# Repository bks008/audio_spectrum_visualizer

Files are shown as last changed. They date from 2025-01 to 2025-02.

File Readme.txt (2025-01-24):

Audio Spectrum Visualizer

Samples stereo analog audio and displays the frequency response on an 8x24 dot LED display.

Inputs:
USB-C PD

R/L RCA at audio line level

USB-C comes in at 20V. 
Supply rails:
3.3V digital supply
5V display supply
+/-6V analog supplies. +/-5V after LDO

R/L RCA has two identical channels
Gain stage
Unity gain stage to add offset (0-5V signal)
Anti Aliasing Low Pass Filter stage
Sampled using ADC121S101 over SPI

Digital Section is anything in the Arduino Nano pinout/form factor. Going with an STM32 NUCLEO-L432KC

Nucleo drives LEDs using I2C to three HT16K33A (borrowing architecture from Adafruit). 

Includes rotary encoder for brightness control and pushbutton.

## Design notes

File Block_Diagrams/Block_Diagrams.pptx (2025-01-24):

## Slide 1

Board to Board Connector

USB-C Connector

Power Converters
(sheet2)

RCA Input

Op Amp Network
(Sheet3)

ADC

STM32 Nucleo

SPI

I2C

LED Matrix Driver

LED Matrix Driver

LED Matrix Driver

LED Matrix Driver

LED Matrix Driver

8x8 LED Matrix

Rotary Encoder

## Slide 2

Power Converter Chain

USB-C Connector

TPS25730SRSMR
USB-C PD Controller

20V Rail

3.3V Buck Converter

REF35250QDBVR
+2.5V V_Ref

REF35125QDBVR
+5V V_Ref

5V Buck Converter

TPS70950DBVR
+5V LDO

+6V Buck Converter

-6V Inverting Buck Converter

TPS72301DBVR
-5V LDO

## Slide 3

https://sound-au.com/project88.htm

Voltage Reference
2.5V

Voltage Reference
5V

RCA Jack Input

Line Level: -10 dBV

OPA2156
Input Buffer

6dB gain

Unity Gain, Adds Offset
From: 0V center
To: 2.5V center

Anti-aliasing Low Pass Filter

ADS7886
ADC

SPI

STM32 Nucleo

Duplicate for second channel

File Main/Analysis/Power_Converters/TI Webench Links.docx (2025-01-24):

TI Webench Links

Inverting Buck 20V -> -6V

https://webench.ti.com/appinfo/webench/scripts/SDP.cgi?ID=741779B27A96B312

Non-Inverting Buck 20V -> 6V

https://webench.ti.com/appinfo/webench/scripts/SDP.cgi?ID=59A415CA2FF1D905

Non-Inverting Buck 20V -> 3.3V

https://webench.ti.com/appinfo/webench/scripts/SDP.cgi?ID=6A7F44F1BA65E24F

Non-Inverting Buck 20V -> 5V

https://webench.ti.com/appinfo/webench/scripts/SDP.cgi?ID=DB2471651018C219

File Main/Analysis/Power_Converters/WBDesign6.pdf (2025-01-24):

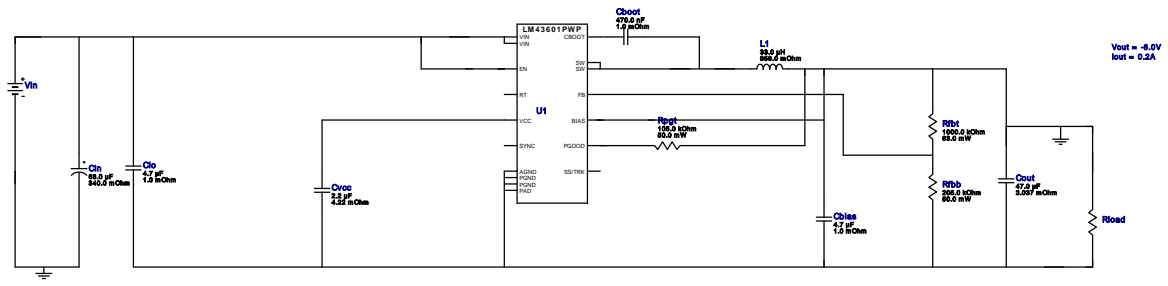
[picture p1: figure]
L1 33.0 µH 959.0 m Ohm; Cboot 470.0 nF; 1.0 m Ohm; Rfbb 205.0 kOhm 50.0 m W; CBOOT; BIAS; SYNC; VIN VIN; VCC; PGOOD; AGND; SS/TRK; PGND PGND PAD; Cin 68.0 µF; 340.0 m Ohm; Cout 47.0 µF; 3.037 m Ohm; Rfbt 1000.0 kOhm; Vout = -6.0V Iout = 0.2A; Rpgt 105.0 kOhm; Cio 4.7 µF; Cvcc; 4.22 m Ohm; Cbias; 4.7 µF 1.0 m Ohm; Vin; Rload

Copyright © 2025, Texas Instruments Incorporated | 1 | ti.com/webench

WEBENCH®
Design Report LM43601PWPR : LM43601PWPR 10V-22V to -6.00V @ 0.2A January 17, 2025 15:35:02 GMT-06:00

## WEBENCH ® Design Report

Design : 6 LM43601PWPR
LM43601PWPR 10V-22V to -6.00V @ 0.2A

VinMin = 10.0V
VinMax = 22.0V
Vout = -6.0V
Iout = 0.2A

Device = LM43601PWPR
Topology = Inverting_Buck_Boost Created = 2024-11-18 17:03:32.722 BOM Cost = $2.27
BOM Count = 11
Total Pd = 0.07W
1. The input capacitor included in the BOM only contains a small filter capacitor that should be placed near the IC. Depending on where the power supply is laid out in the system additional bulk capacitance may need to be added to filter the line ripple.
2. If there is no VinTyp specified, WEBENCH will use the VinMax value. To change the VinTyp value, click on the "Change Design Inputs" button under the Optimization Tuning knob. In some applications, while the design requires the input voltage to be a wide range, for a majority of the time, it is operating at a much lower voltage than the maximum input voltage. Sizing the inductor based on the maximum input voltage may yield an inductance much larger than typically needed, causing a larger footprint for the overall design. At the same time, components such as the input capacitor must be rated based on the maximum input voltage. WEBENCH now supports the use of this additional input voltage specification.

## Electrical BOM

Name | Manufacturer | Part Number | Properties | Qty Price | Footprint
Cbias | Taiyo Yuden | LMK212B7475KG-T (http://www.yuden.co.jp/ut/product/pdf/djmk%5Fe.pdf) Series= X7R | Cap= 4.7 uF ESR= 1.0 mOhm VDC= 10.0 V IRMS= 0.0 A
1 | $0.04
| | | | | 0805 7 mm²
Cboot | MuRata | GRM155R60J474KE19D (http://search.murata.co.jp/Ceramy/PnsearchViewAction.do) Series= X5R

Cap= 470.0 nF
ESR= 1.0 mOhm
VDC= 6.3 V
IRMS= 0.0 A

1 $0.01
0402 3 mm²
Cin | Nichicon | UUD1V680MCL1GS (http://products.nichicon.co.jp/en/pdf/XJA043/e%2Dud.pdf) Series= uD

Cap= 68.0 uF
ESR= 340.0 mOhm
VDC= 35.0 V
IRMS= 280.0 mA

1 $0.10

SM_RADIAL_6.3BMM 80
mm²
Cio | TDK | C2012X5R1H475K125AB Series= X5R

Cap= 4.7 uF
ESR= 1.0 mOhm
VDC= 50.0 V
IRMS= 4.3 A

1 $0.12
0805 7 mm²
Cout | MuRata | GRM32ER61C476KE15L (http://psearch.en.murata.com/capacitor/result/smd/?status%3Dall%26pid%3DGRM32ER61C476KE15L) Series= X5R

Cap= 47.0 uF
ESR= 3.037 mOhm
VDC= 16.0 V
IRMS= 4.59346 A

1 $0.17
1210_280 15 mm²
Cvcc | MuRata | GRM21BR71A225KA01L (http://psearch.en.murata.com/capacitor/result/smd/?status%3Dall%26pid%3DGRM21BR71A225KA01L) Series= X7R

Cap= 2.2 uF
ESR= 4.22 mOhm
VDC= 10.0 V
IRMS= 2.08454 A

1 $0.03
0805 7 mm²
L1 | Bourns | SRN3015-330M (http://www.bourns.com/data/global/pdfs/SRN3015.pdf) | L= 33.0 µH 959.0 mOhm
1 | $0.22

SRN3015 16 mm²
Rfbb | Yageo | RC0201FR-07205KL (http://www.yageo.com/exep/pages/download/literatures/PYu%2DR%5FMarking%5F2.pdf) Series= ? | Res= 205.0 kOhm Power= 50.0 mW Tolerance= 1.0%
1 | $0.01
0201 2 mm²

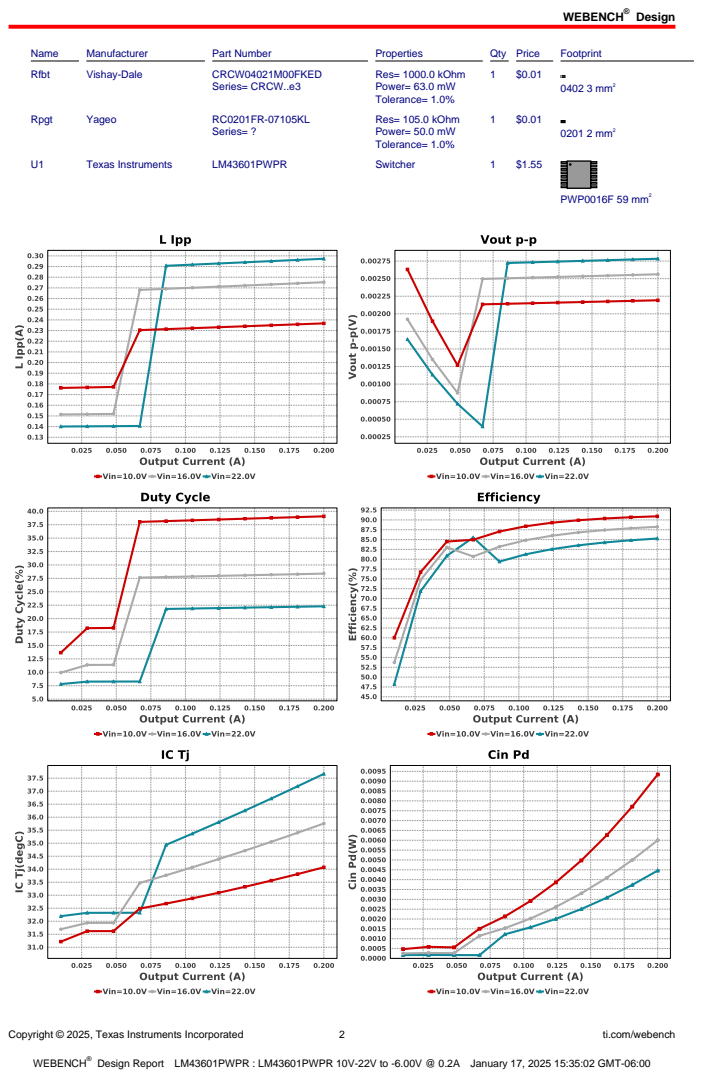
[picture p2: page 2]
Design; Copyright © 2025, Texas Instruments Incorporated; ti.com/webench; Name; Manufacturer; Part Number; Properties; Qty Price; Footprint; Rfbt; Vishay-Dale; CRCW04021M00FKED; Series= CRCW..e3; Res= 1000.0 kOhm Power= 63.0 mW Tolerance= 1.0%; 0402 3 mm²; Rpgt; Yageo; Series= ?; Res= 105.0 kOhm Power= 50.0 mW Tolerance= 1.0%; 0201 2 mm²; Texas Instruments; LM43601PWPR; Switcher; PWP0016F 59 mm²

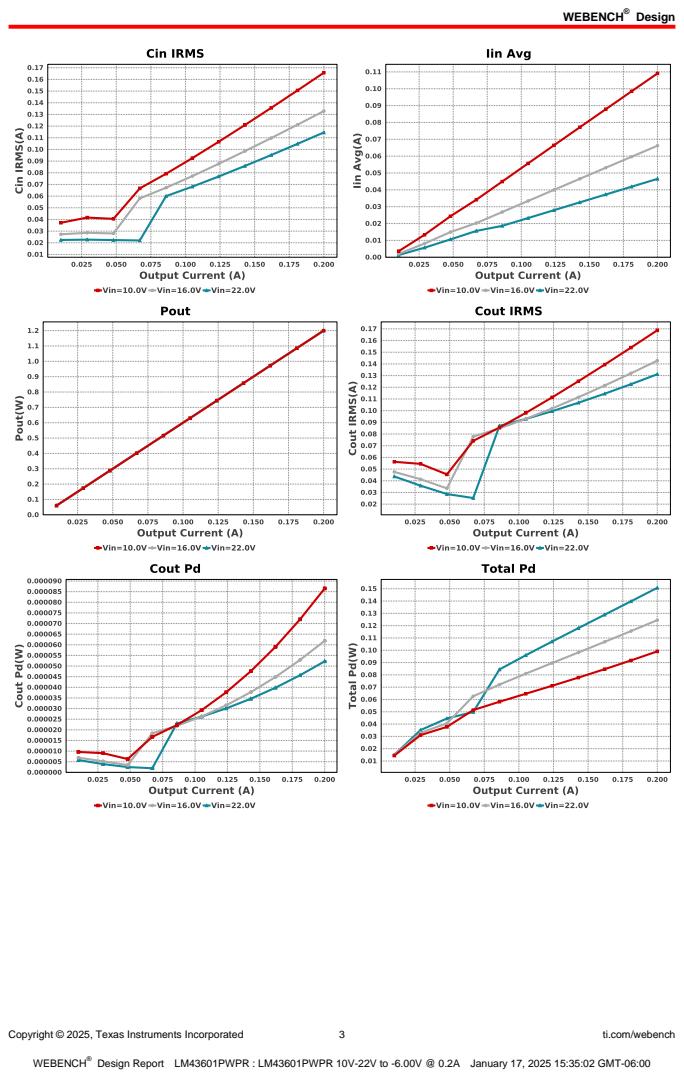
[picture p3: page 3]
Copyright © 2025, Texas Instruments Incorporated; ti.com/webench

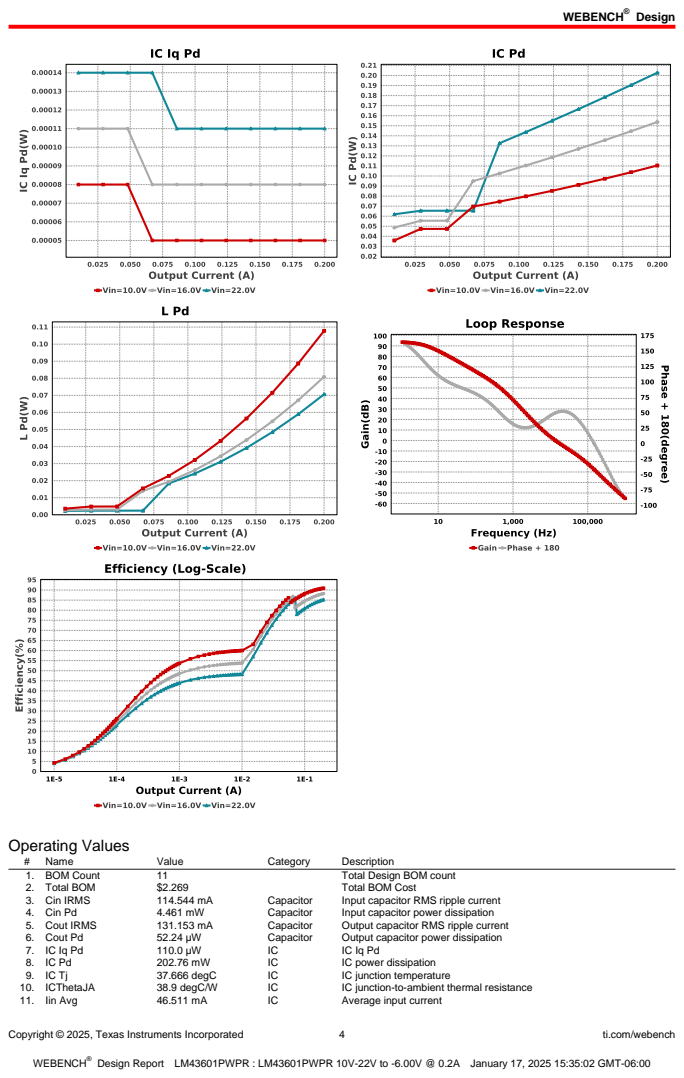
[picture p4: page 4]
Copyright © 2025, Texas Instruments Incorporated; ti.com/webench; Operating Values; Name; Value; Category; Description; 1. BOM Count; Total Design BOM count; 2. Total BOM; Total BOM Cost; 3. Cin IRMS; Capacitor; Input capacitor RMS ripple current; 4. Cin Pd; Input capacitor power dissipation; 5. Cout IRMS; Output capacitor RMS ripple current; 6. Cout Pd; Output capacitor power dissipation; IC power dissipation; 37.666 degC; IC junction temperature; 10. ICThetaJA; 38.9 degC/W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

Copyright © 2025, Texas Instruments Incorporated | 5 | ti.com/webench
# | Name | Value | Category | Description

12. L Ipp | 297.293 mA | Inductor | Peak-to-peak inductor ripple current
13. L Pd | 70.597 mW | Inductor | Inductor power dissipation
14. Cin Pd | 4.461 mW | Power | Input capacitor power dissipation
15. Cout Pd | 52.24 µW | Power | Output capacitor power dissipation
16. IC Pd | 202.76 mW | Power | IC power dissipation
17. L Pd | 70.597 mW | Power | Inductor power dissipation
18. Total Pd | 68.515 mW | Power | Total Power Dissipation
19. Cross Freq | 13.664 kHz | System
| | | Information | Bode plot crossover frequency
20. Duty Cycle | 22.297 % | System
| | | Information | Duty cycle
21. Efficiency | 85.269 % | System
| | | Information | Steady state efficiency
22. FootPrint | 200.0 mm² | System
| | | Information | Total Foot Print Area of BOM components
23. Frequency | 500.0 kHz | System
| | | Information | Switching frequency
24. Gain Marg | -27.732 dB | System
| | | Information | Bode Plot Gain Margin
25. Iout | 200.0 mA | System
| | | Information | Iout operating point
26. Low Freq Gain | 93.543 dB | System
| | | Information | Gain at 1Hz
27. Mode | CCM | System
| | | Information | Conduction Mode
28. Phase Marg | 50.083 deg | System
| | | Information | Bode Plot Phase Margin
29. Pout | 1.2 W | System
| | | Information | Total output power
30. Vin | 10.0 V | System
| | | Information | Vin operating point
31. Vout | -6.0 V | System
| | | Information | Operational Output Voltage
32. Vout Actual | 5.972 V | System
| | | Information | Vout Actual calculated based on selected voltage divider resistors
33. Vout Tolerance | 3.978 % | System
| | | Information | Vout Tolerance based on IC Tolerance (no load) and voltage divider resistors if applicable
34. Vout p-p | 2.783 mV | System
| | | Information | Peak-to-peak output ripple voltage

## Design Inputs

Name | Value | Description
| Iout | | 200.0 m | Maximum Output Current
VinMax | 22.0 | Maximum input voltage
VinMin | 10.0 | Minimum input voltage
Vout | -6.0 | Output Voltage
| base_pn | | LM43601 | Base Product Number
source | DC | Input Source Type
Ta | 30.0 | Ambient temperature


Copyright © 2025, Texas Instruments Incorporated | 6 | ti.com/webench

## Assembly

## Component Testing

Some published data on components in datasheets such as Capacitor ESR and Inductor DC resistance is based on conservative values that will guarantee that the components always exceed the specification. For design purposes it is usually better to work with typical values. Since this data is not always available it is a good practice to measure the Capacitance and ESR values of Cin and Cout, and the inductance and DC resistance of L1 before assembly of the board. Any large discrepancies in values should be electrically simulated in WEBENCH to check for instabilities and thermally simulated in WebTHERM to make sure critical temperatures are not exceeded.

## Soldering Component to Board

If board assembly is done in house it is best to tack down one terminal of a component on the board then solder the other terminal. For surface mount parts with large tabs, such as the DPAK, the tab on the back of the package should be pre-tinned with solder, then tacked into place by one of the pins. To solder the tab town to the board place the iron down on the board while resting against the tab, heating both surfaces simultaneously. Apply light pressure to the top of the plastic case until the solder flows around the part and the part is flush with the PCB. If the solder is not flowing around the board you may need a higher wattage iron (generally 25W to 30W is enough).

## Initial Startup of Circuit

It is best to initially power up the board by setting the input supply voltage to the lowest operating input voltage 10.0V and set the input supply's current limit to zero. With the input supply off connect up the input supply to Vin and GND. Connect a digital volt meter and a load if needed to set the minimum Iout of the design from Vout and GND. Turn on the input supply and slowly turn up the current limit on the input supply.
If the voltage starts to rise on the input supply continue increasing the input supply current limit while watching the output voltage. If the current increases on the input supply, but the voltage remains near zero, then there may be a short or a component misplaced on the board. Power down the board and visually inspect for solder bridges and recheck the diode and capacitor polarities. Once the power supply circuit is operational then more extensive testing may include full load testing, transient load and line tests to compare with simulation results.

## Load Testing

The setup is the same as the initial startup, except that an additional digital voltmeter is connected between Vin and GND, a load is connected between Vout and GND and a current meter is connected in series between Vout and the load. The load must be able to handle at least rated output power + 50% ( 7.5 watts for this design). Ideally the load is supplied in the form of a variable load test unit. It can also be done in the form of suitably large power resistors. When using an oscilloscope to measure waveforms on the prototype board, the ground leads of the oscilloscope probes should be as short as possible and the area of the loop formed by the ground lead should be kept to a minimum. This will help reduce ground lead inductance and eliminate EMI noise that is not actually present in the circuit.

## Design Assistance

1. Master key : C6AE7176C9723757[v1]
2. LM43601 Product Folder : http://www.ti.com/product/LM43601 : contains the data sheet and other resources.

Copyright © 2025, Texas Instruments Incorporated | 7 | ti.com/webench

Important Notice and Disclaimer

TI provides technical and reliability data (including datasheets), design resources (including reference designs), application or other design advice, web tools, safety information, and other resources AS IS and with all faults, and disclaims all warranties. These resources are intended for skilled developers designing with TI products. You are solely responsible for (1) selecting the appropriate TI products for your application, (2) designing, validating and testing your application, and (3) ensuring your application meets applicable standards, and any other safety, security, or other requirements.

These resources are subject to change without notice. TI grants you permission to use these resources only for development of an application that uses the TI products described in the resource. Other reproduction and display of these resources is prohibited. No license is granted to any other TI intellectual property right or to any third party intellectual property right. TI disclaims responsibility for, and you will fully indemnify TI and its representatives against, any claims, damages, costs, losses, and liabilities arising out of your use of these resources.

Providing these resources does not expand or otherwise alter TI's applicable Terms of Sale or other applicable terms available either on ti.com or provided in conjunction with TI products.

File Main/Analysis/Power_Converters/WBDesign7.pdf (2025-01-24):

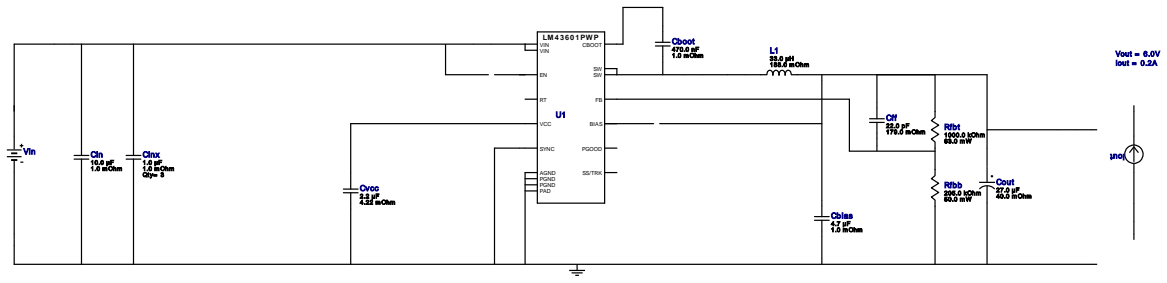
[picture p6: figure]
Cout 27.0 µF; 40.0 m Ohm; L1 33.0 µH 188.0 m Ohm; Rfbt 1000.0 kOhm; Cinx 1.0 µF 1.0 m Ohm; Qty= 3; Rfbb; 205.0 kOhm 50.0 m W; Cboot 470.0 nF; 1.0 m Ohm; Cin 10.0 µF 1.0 m Ohm; Cvcc 2.2 µF 4.22 m Ohm; CBOOT; BIAS; SYNC; VIN VIN; VCC; PGOOD; AGND; SS/TRK; PGND PGND PAD; Vout = 6.0V Iout = 0.2A; Cbias 4.7 µF 1.0 m Ohm; Cff 22.0 pF; 179.0 m Ohm; Vin; Iout

Copyright © 2025, Texas Instruments Incorporated | 1 | ti.com/webench

WEBENCH®
Design Report LM43601PWPR : LM43601PWPR 10V-22V to 6.00V @ 0.2A January 17, 2025 15:37:10 GMT-06:00

## WEBENCH ® Design Report

Design : 7 LM43601PWPR
LM43601PWPR 10V-22V to 6.00V @ 0.2A

VinMin = 10.0V
VinMax = 22.0V
Vout = 6.0V
Iout = 0.2A

Device = LM43601PWPR
Topology = Buck
Created = 2024-11-18 17:06:33.048 BOM Cost = $2.77
BOM Count = 13
Total Pd = 0.15W
1. The input capacitor included in the BOM only contains a small filter capacitor that should be placed near the IC. Depending on where the power supply is laid out in the system additional bulk capacitance may need to be added to filter the line ripple.
2. If there is no VinTyp specified, WEBENCH will use the VinMax value. To change the VinTyp value, click on the "Change Design Inputs" button under the Optimization Tuning knob. In some applications, while the design requires the input voltage to be a wide range, for a majority of the time, it is operating at a much lower voltage than the maximum input voltage. Sizing the inductor based on the maximum input voltage may yield an inductance much larger than typically needed, causing a larger footprint for the overall design. At the same time, components such as the input capacitor must be rated based on the maximum input voltage. WEBENCH now supports the use of this additional input voltage specification.

## Electrical BOM

Name | Manufacturer | Part Number | Properties | Qty Price | Footprint
Cbias | Taiyo Yuden | LMK212B7475KG-T (http://www.yuden.co.jp/ut/product/pdf/djmk%5Fe.pdf) Series= X7R | Cap= 4.7 uF ESR= 1.0 mOhm VDC= 10.0 V IRMS= 0.0 A
1 | $0.04
| | | | | 0805 7 mm²
Cboot | MuRata | GRM155R60J474KE19D (http://search.murata.co.jp/Ceramy/PnsearchViewAction.do) Series= X5R

Cap= 470.0 nF
ESR= 1.0 mOhm
VDC= 6.3 V
IRMS= 0.0 A

1 $0.01
0402 3 mm²
Cff | Kemet | C0805C220J5GACTU (http://capacitoredge.kemet.com/capedge2/DataSheet/Datasheet%2DC0805C220J5GACTU.pdf?pn%3DC0805C220J5GACTU) Series= C0G/NP0

Cap= 22.0 pF
ESR= 179.0 mOhm
VDC= 50.0 V
IRMS= 464.0 mA

1 $0.01
0805 7 mm²
Cin | TDK | C3225X7R1H106M250AC Series= X7R

Cap= 10.0 uF
ESR= 1.0 mOhm
VDC= 50.0 V
IRMS= 5.0 A

1 $0.27
1210 15 mm²
Cinx | Taiyo Yuden | GMK212B7105KG-T (http://www.yuden.co.jp/ut/product/pdf/djmk%5Fe.pdf) Series= X7R

Cap= 1.0 uF
ESR= 1.0 mOhm
VDC= 35.0 V
IRMS= 0.0 A

3 $0.04
0805 7 mm²
Cout | Panasonic | 25SVPF27MX Series= SVPF

Cap= 27.0 uF
ESR= 40.0 mOhm
VDC= 25.0 V
IRMS= 2.45 A

1 $0.47

CAPSMT_62_E61 53 mm²

Cvcc | MuRata | GRM21BR71A225KA01L (http://psearch.en.murata.com/capacitor/result/smd/?status%3Dall%26pid%3DGRM21BR71A225KA01L) Series= X7R

Cap= 2.2 uF
ESR= 4.22 mOhm
VDC= 10.0 V
IRMS= 2.08454 A

1 $0.03
0805 7 mm²
L1 | Bourns | SRN6045-330M (http://www.bourns.com/data/global/pdfs/SRN6045.pdf) | L= 33.0 µH 188.0 mOhm
1 | $0.25

SRN6045 64 mm²

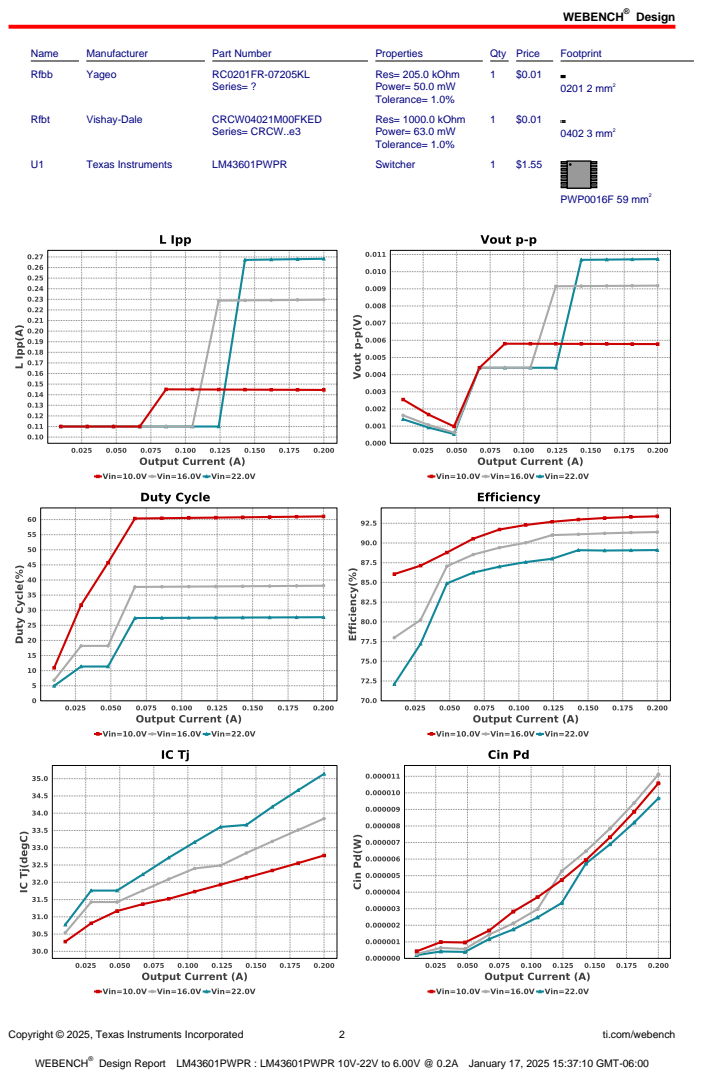
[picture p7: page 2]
Design; Copyright © 2025, Texas Instruments Incorporated; ti.com/webench; Name; Manufacturer; Part Number; Properties; Qty Price; Footprint; Rfbb; Yageo; Series= ?; Res= 205.0 kOhm Power= 50.0 mW Tolerance= 1.0%; 0201 2 mm²; Rfbt; Vishay-Dale; CRCW04021M00FKED; Series= CRCW..e3; Res= 1000.0 kOhm Power= 63.0 mW Tolerance= 1.0%; 0402 3 mm²; Texas Instruments; LM43601PWPR; Switcher; PWP0016F 59 mm²

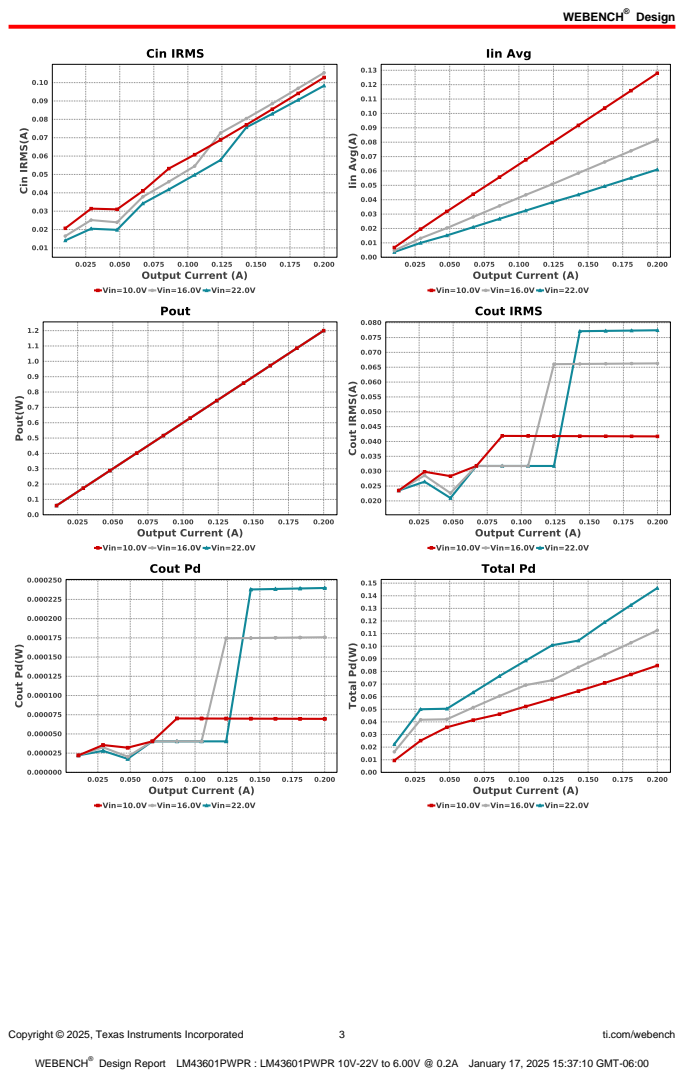
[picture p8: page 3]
Copyright © 2025, Texas Instruments Incorporated; ti.com/webench

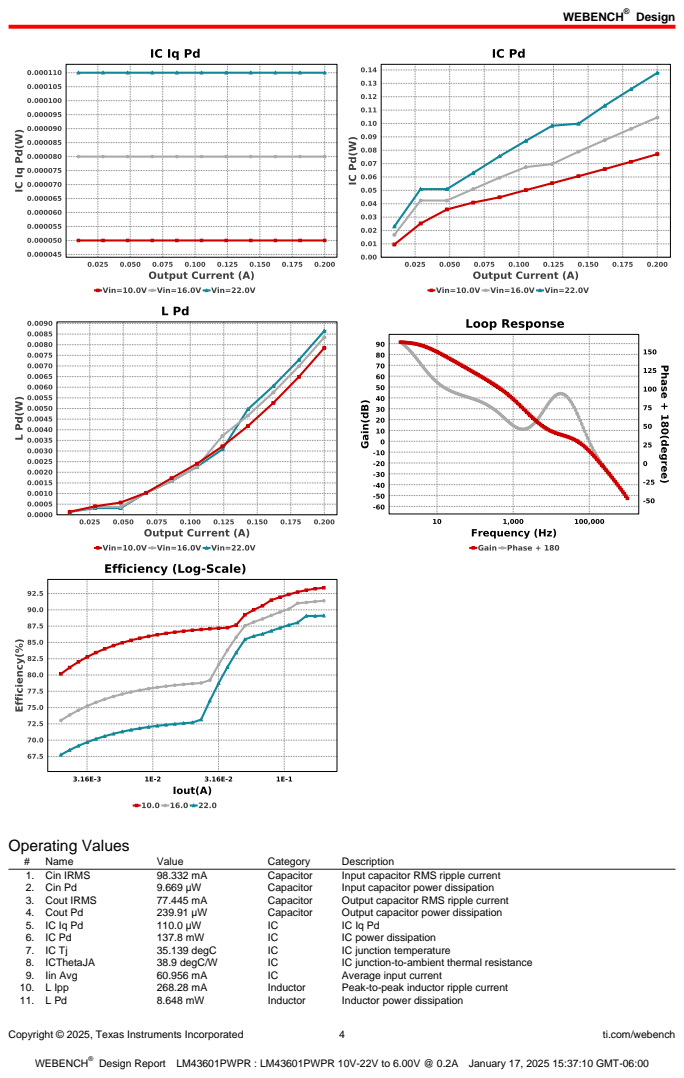
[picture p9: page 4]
Copyright © 2025, Texas Instruments Incorporated; ti.com/webench; Operating Values; Name; Value; Category; Description; 1. Cin IRMS; Capacitor; Input capacitor RMS ripple current; 2. Cin Pd; Input capacitor power dissipation; 3. Cout IRMS; Output capacitor RMS ripple current; 4. Cout Pd; Output capacitor power dissipation; IC power dissipation; 35.139 degC; IC junction temperature; 8. ICThetaJA; 38.9 degC/W; IC junction-to-ambient thermal resistance; 9. Iin Avg; Average input current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

Copyright © 2025, Texas Instruments Incorporated | 5 | ti.com/webench
# | Name | Value | Category | Description

12. Cin Pd | 9.669 µW | Power | Input capacitor power dissipation
13. Cout Pd | 239.91 µW | Power | Output capacitor power dissipation
14. IC Pd | 137.8 mW | Power | IC power dissipation
15. L Pd | 8.648 mW | Power | Inductor power dissipation
16. Total Pd | 146.105 mW | Power | Total Power Dissipation
17. BOM Count | 13 | System
| | | Information | Total Design BOM count
18. Cross Freq | 48.533 kHz | System
| | | Information | Bode plot crossover frequency
19. Duty Cycle | 27.687 % | System
| | | Information | Duty cycle
20. Efficiency | 89.105 % | System
| | | Information | Steady state efficiency
21. FootPrint | 239.0 mm² | System
| | | Information | Total Foot Print Area of BOM components
22. Frequency | 500.0 kHz | System
| | | Information | Switching frequency
23. Gain Marg | -22.122 dB | System
| | | Information | Bode Plot Gain Margin
24. Iout | 200.0 mA | System
| | | Information | Iout operating point
25. Low Freq Gain | 91.3 dB | System
| | | Information | Gain at 1Hz
26. Mode | CCM | System
| | | Information | Conduction Mode
27. Phase Marg | 66.734 deg | System
| | | Information | Bode Plot Phase Margin
28. Pout | 1.2 W | System
| | | Information | Total output power
29. Total BOM | $2.77 | System
| | | Information | Total BOM Cost
30. Vin | 22.0 V | System
| | | Information | Vin operating point
31. Vout | 6.0 V | System
| | | Information | Operational Output Voltage
32. Vout Actual | 5.972 V | System
| | | Information | Vout Actual calculated based on selected voltage divider resistors
33. Vout Tolerance | 3.978 % | System
| | | Information | Vout Tolerance based on IC Tolerance (no load) and voltage divider resistors if applicable
34. Vout p-p | 10.731 mV | System
| | | Information | Peak-to-peak output ripple voltage

## Design Inputs

Name | Value | Description
| Iout | | 200.0 m | Maximum Output Current
VinMax | 22.0 | Maximum input voltage
VinMin | 10.0 | Minimum input voltage
Vout | 6.0 | Output Voltage
| base_pn | | LM43601 | Base Product Number
source | DC | Input Source Type
Ta | 30.0 | Ambient temperature


Copyright © 2025, Texas Instruments Incorporated | 6 | ti.com/webench

## Assembly

## Component Testing

Some published data on components in datasheets such as Capacitor ESR and Inductor DC resistance is based on conservative values that will guarantee that the components always exceed the specification. For design purposes it is usually better to work with typical values. Since this data is not always available it is a good practice to measure the Capacitance and ESR values of Cin and Cout, and the inductance and DC resistance of L1 before assembly of the board. Any large discrepancies in values should be electrically simulated in WEBENCH to check for instabilities and thermally simulated in WebTHERM to make sure critical temperatures are not exceeded.

## Soldering Component to Board

If board assembly is done in house it is best to tack down one terminal of a component on the board then solder the other terminal. For surface mount parts with large tabs, such as the DPAK, the tab on the back of the package should be pre-tinned with solder, then tacked into place by one of the pins. To solder the tab town to the board place the iron down on the board while resting against the tab, heating both surfaces simultaneously. Apply light pressure to the top of the plastic case until the solder flows around the part and the part is flush with the PCB. If the solder is not flowing around the board you may need a higher wattage iron (generally 25W to 30W is enough).

## Initial Startup of Circuit

It is best to initially power up the board by setting the input supply voltage to the lowest operating input voltage 10.0V and set the input supply's current limit to zero. With the input supply off connect up the input supply to Vin and GND. Connect a digital volt meter and a load if needed to set the minimum Iout of the design from Vout and GND. Turn on the input supply and slowly turn up the current limit on the input supply.
If the voltage starts to rise on the input supply continue increasing the input supply current limit while watching the output voltage. If the current increases on the input supply, but the voltage remains near zero, then there may be a short or a component misplaced on the board. Power down the board and visually inspect for solder bridges and recheck the diode and capacitor polarities. Once the power supply circuit is operational then more extensive testing may include full load testing, transient load and line tests to compare with simulation results.

## Load Testing

The setup is the same as the initial startup, except that an additional digital voltmeter is connected between Vin and GND, a load is connected between Vout and GND and a current meter is connected in series between Vout and the load. The load must be able to handle at least rated output power + 50% ( 7.5 watts for this design). Ideally the load is supplied in the form of a variable load test unit. It can also be done in the form of suitably large power resistors. When using an oscilloscope to measure waveforms on the prototype board, the ground leads of the oscilloscope probes should be as short as possible and the area of the loop formed by the ground lead should be kept to a minimum. This will help reduce ground lead inductance and eliminate EMI noise that is not actually present in the circuit.

## Design Assistance

1. Master key : C6AE7176C9723757[v1]
2. LM43601 Product Folder : http://www.ti.com/product/LM43601 : contains the data sheet and other resources.

Copyright © 2025, Texas Instruments Incorporated | 7 | ti.com/webench

Important Notice and Disclaimer

TI provides technical and reliability data (including datasheets), design resources (including reference designs), application or other design advice, web tools, safety information, and other resources AS IS and with all faults, and disclaims all warranties. These resources are intended for skilled developers designing with TI products. You are solely responsible for (1) selecting the appropriate TI products for your application, (2) designing, validating and testing your application, and (3) ensuring your application meets applicable standards, and any other safety, security, or other requirements.

These resources are subject to change without notice. TI grants you permission to use these resources only for development of an application that uses the TI products described in the resource. Other reproduction and display of these resources is prohibited. No license is granted to any other TI intellectual property right or to any third party intellectual property right. TI disclaims responsibility for, and you will fully indemnify TI and its representatives against, any claims, damages, costs, losses, and liabilities arising out of your use of these resources.

Providing these resources does not expand or otherwise alter TI's applicable Terms of Sale or other applicable terms available either on ti.com or provided in conjunction with TI products.

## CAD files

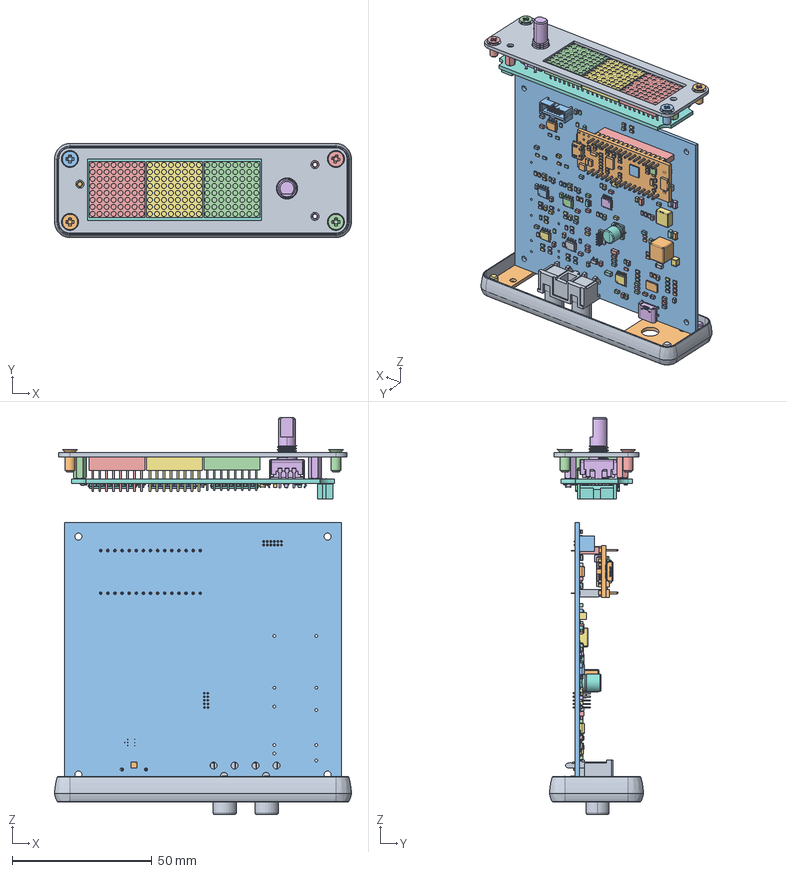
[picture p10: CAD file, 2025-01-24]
CAD/Final_Assy.FCStd
106.1 x 33.6 x 141.8 mm
L Bezel Open001
1455 screw
1455 screw001
1455 screw002
1455 screw003
1455 screw004
1455 screw005
1455 screw006
1455 screw007
mb1180c
qfn_STM32L412KBU6U
LD39050PU33R-Nucleo
STM32F103CBT6-nucleo
header x2
R_0805_2012Metric
SSOP_24_39x87mm_P0635mm
C_0805_2012Metric
C_0805_2012Metric225
R_0805_2012Metric268
R_0805_2012Metric269
D_SOD_523
R_0805_2012Metric270
C_0805_2012Metric226
SSOP_24_39x87mm_P0635mm001
R_0805_2012Metric271
R_0805_2012Metric272
R_0805_2012Metric273
D_SOD_524
R_0805_2012Metric274
D_SOD_525
C_0805_2012Metric227
C_0805_2012Metric228
C_0805_2012Metric229
R_0805_2012Metric275
C_0805_2012Metric230
R_0805_2012Metric276
R_0805_2012Metric277
C_0805_2012Metric231
R_0805_2012Metric278
SHF-106-01-L-D-TH-TR
R_0805_2012Metric279
C_0805_2012Metric232
SSOP_24_39x87mm_P0635mm002
PEC11R-4215F-S0024
_autosave-Display_PCB
C_0805_2012Metric242
C_0805_2012Metric243
C_0805_2012Metric244
TSSOP_16_44x5mm_P065mm
R_0805_2012Metric293
R_0805_2012Metric294
R_0805_2012Metric295
R_0805_2012Metric296
R_0805_2012Metric297
R_0805_2012Metric298
R_0805_2012Metric299
R_0805_2012Metric300
SOIC_8_39x49mm_P127mm
C_0805_2012Metric245
R_0805_2012Metric301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

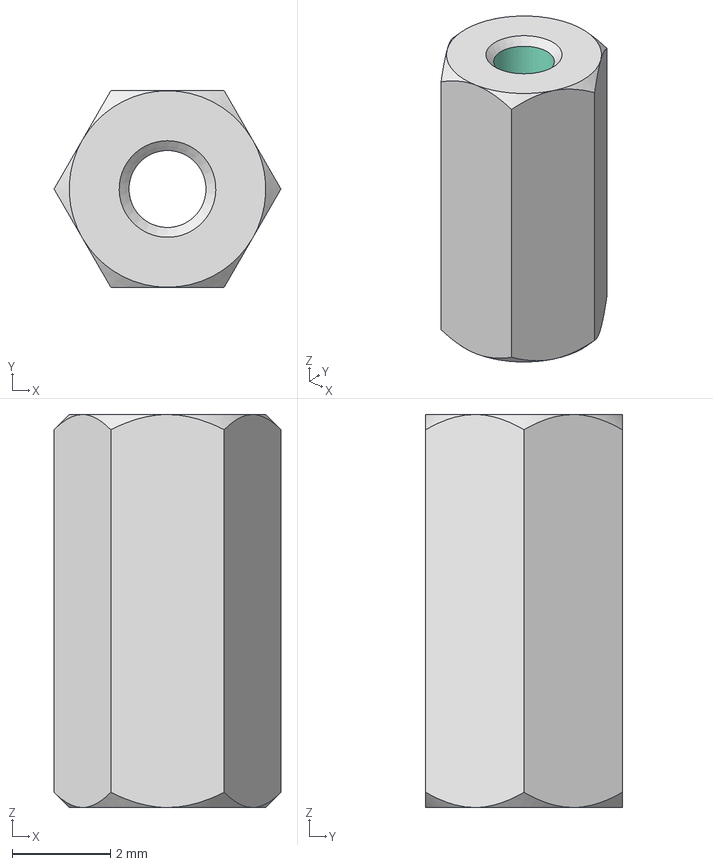
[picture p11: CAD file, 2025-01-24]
CAD/Download_STEP_970080244 (rev1).stp
4.62 x 4.00 x 8.00 mm

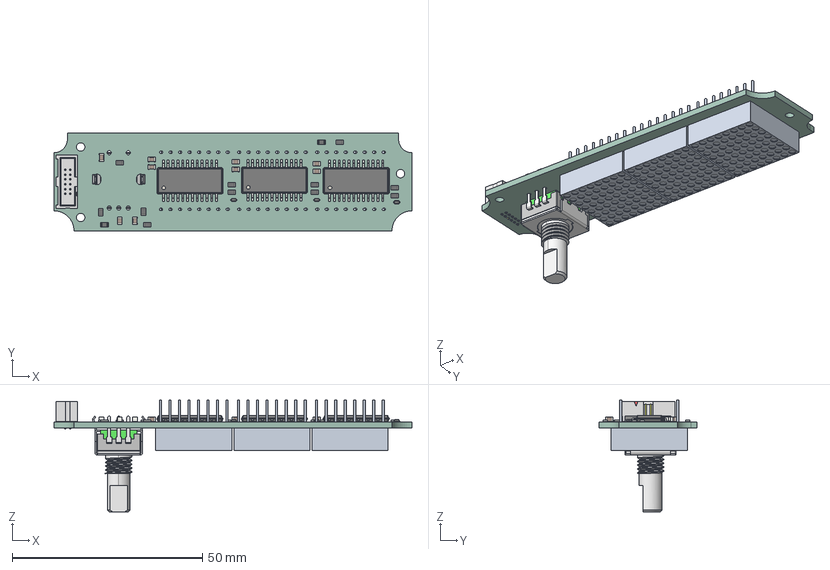
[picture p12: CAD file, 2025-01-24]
Display/Display.step
94.0 x 25.6 x 29.4 mm
R_0805_2012Metric x 13
SSOP_24_39x87mm_P0635mm x 3
C_0805_2012Metric x 9
D_SOD_523 x 3
SHF-106-01-L-D-TH-TR
PEC11R-4215F-S0024
_autosave-Display_PCB

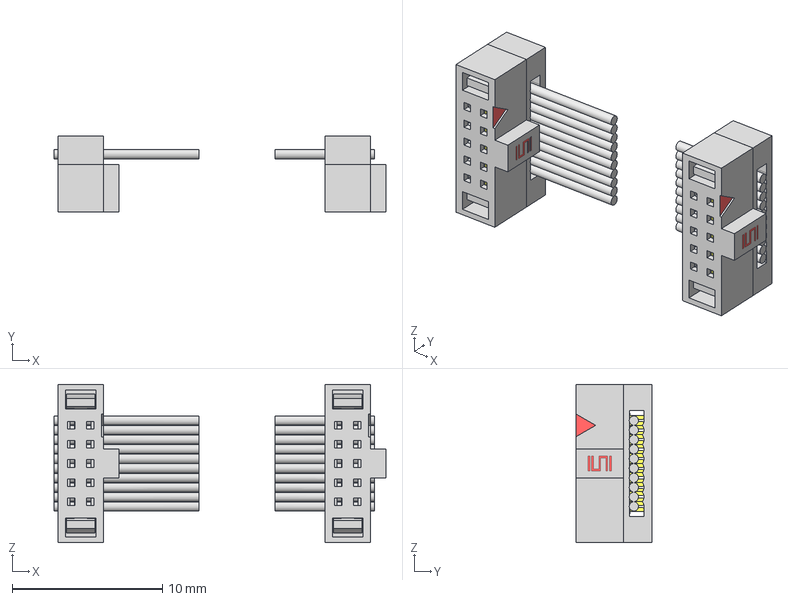
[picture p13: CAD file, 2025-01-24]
CAD/FFSD-05-D-06.00-01-N.stp
22.1 x 5.08 x 10.5 mm
FFSD-050LB x 2
FFSD-05()ub
FFSD-05pin x 4
FFSD-050se_ub

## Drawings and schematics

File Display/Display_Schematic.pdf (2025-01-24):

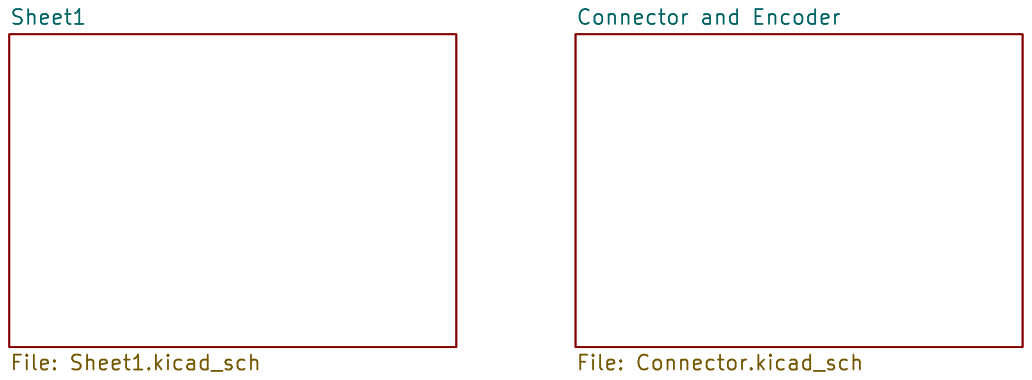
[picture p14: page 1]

Id: 1/3 Title: File: Display.kicad_sch Sheet: /

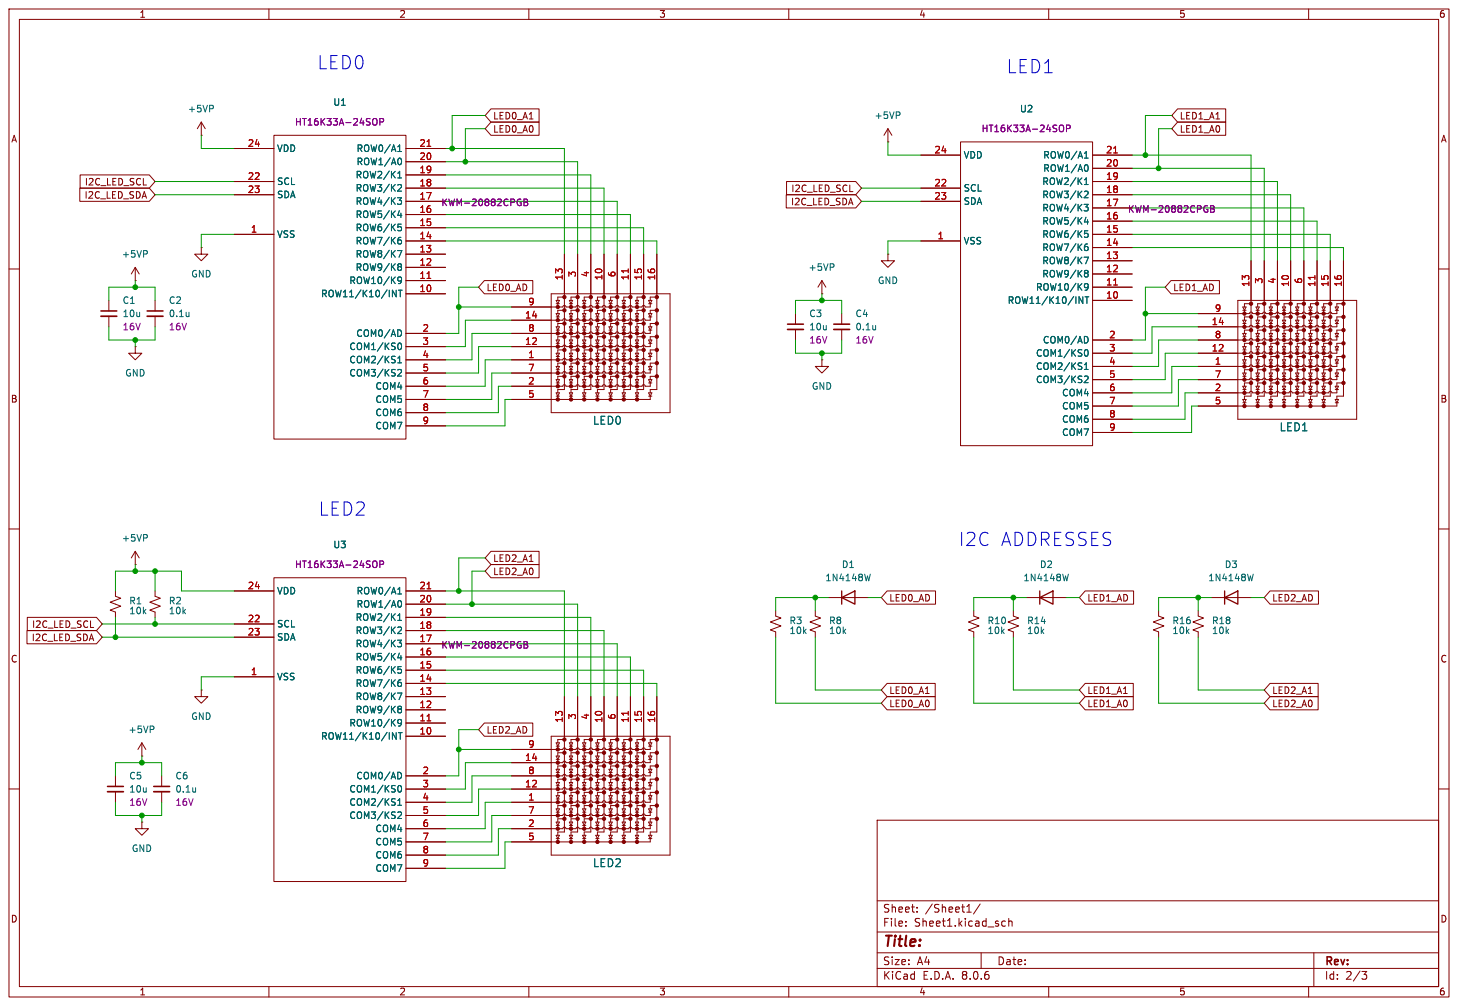
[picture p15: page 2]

Id: 2/3 Title: File: Sheet1.kicad_sch Sheet: /Sheet1/

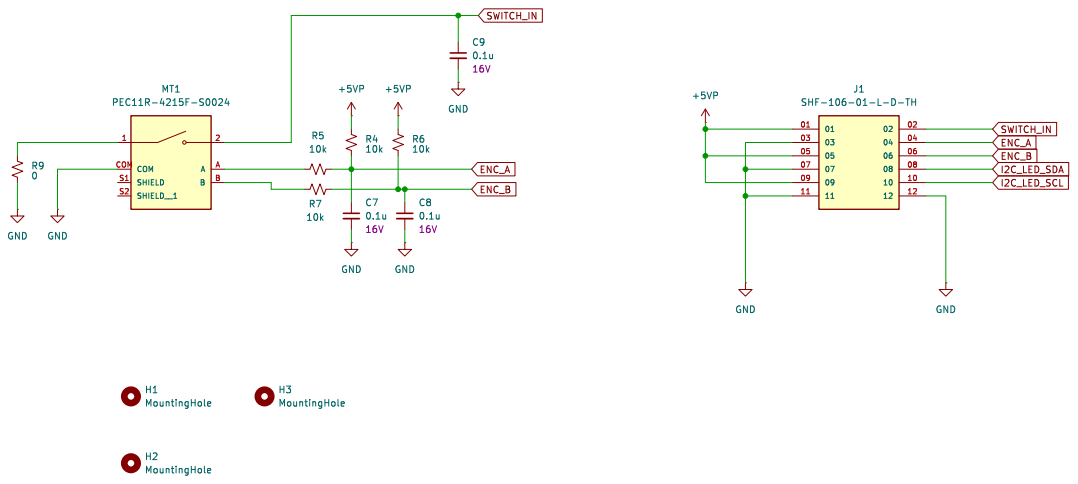
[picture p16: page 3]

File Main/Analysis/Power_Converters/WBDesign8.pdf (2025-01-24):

## WEBENCH ® Design Report

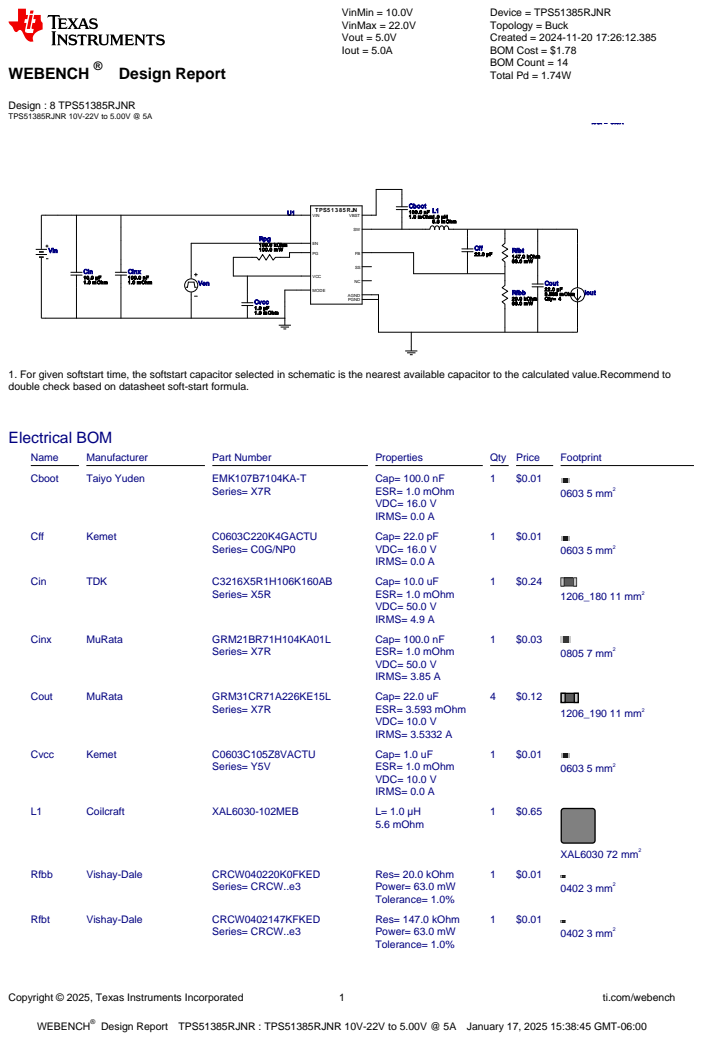
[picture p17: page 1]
Copyright © 2025, Texas Instruments Incorporated; ti.com/webench; WEBENCH®; Design : 8 TPS51385RJNR TPS51385RJNR 10V-22V to 5.00V @ 5A; VinMin = 10.0V VinMax = 22.0V Vout = 5.0V Iout = 5.0A; Device = TPS51385RJNR Topology = Buck Created = 2024-11-20 17:26:12.385 BOM Cost = $1.78 BOM Count = 14 Total Pd = 1.74W; TPS5 1 3 8 5 RJN VIN; PGND; VBST; VCC; AGND; MODE; Cinx 100.0 nF 1.0 m Ohm; Cin 10.0 µF; 1.0 m Ohm; Ven; Cvcc 1.0 µF 1.0 m Ohm; Cff 22.0 pF; L1 1.0 µH 5.6 m Ohm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

1. For given softstart time, the softstart capacitor selected in schematic is the nearest available capacitor to the calculated value.Recommend to
double check based on datasheet soft-start formula.

Design Report TPS51385RJNR : TPS51385RJNR 10V-22V to 5.00V @ 5A January 17, 2025 15:38:45 GMT-06:00

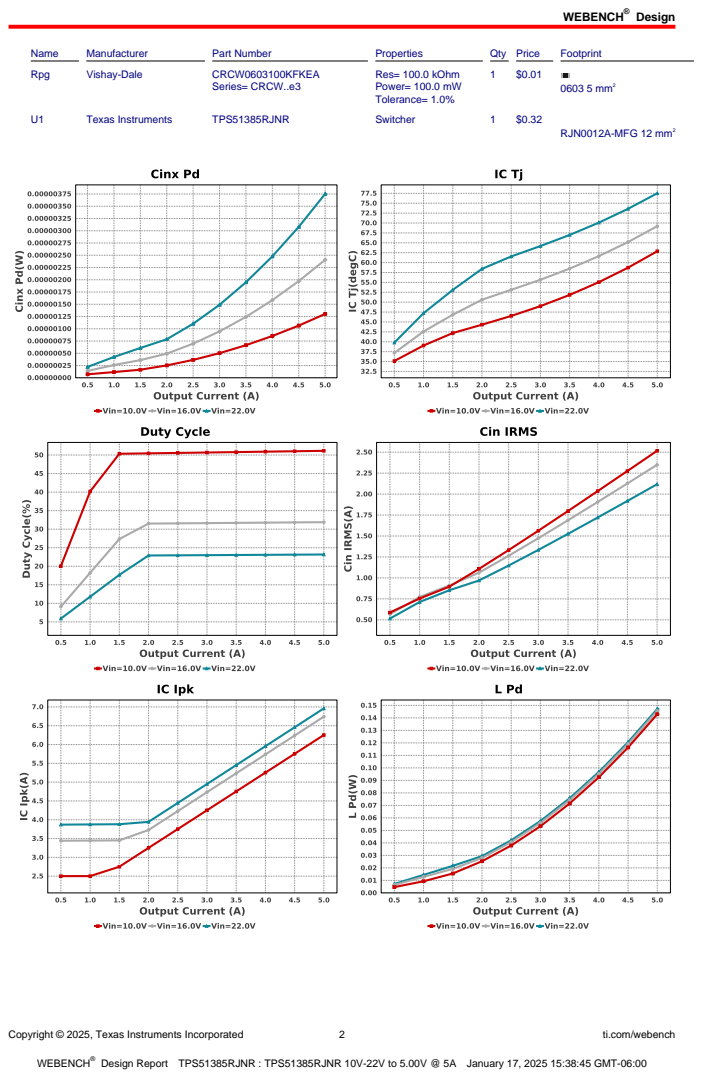
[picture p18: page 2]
Design; Copyright © 2025, Texas Instruments Incorporated; ti.com/webench; Name; Manufacturer; Part Number; Properties; Qty Price; Footprint; Rpg; Vishay-Dale; CRCW0603100KFKEA; Series= CRCW..e3; Res= 100.0 kOhm Power= 100.0 mW Tolerance= 1.0%; 0603 5 mm²; Texas Instruments; TPS51385RJNR; Switcher; RJN0012A-MFG 12 mm²

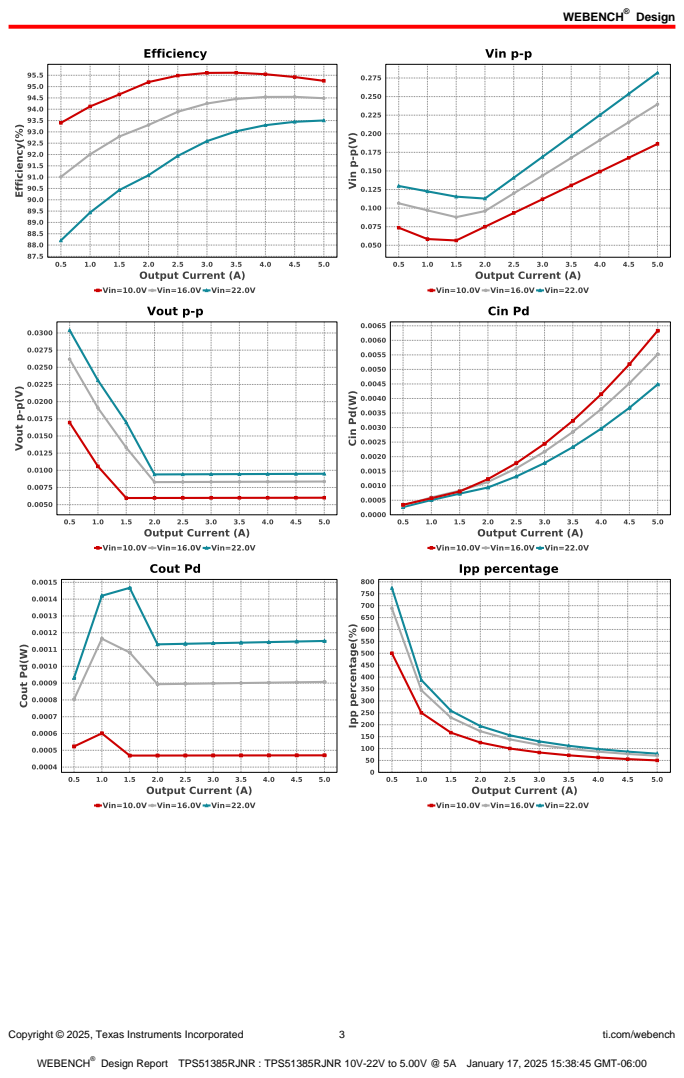
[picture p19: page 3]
Copyright © 2025, Texas Instruments Incorporated; ti.com/webench

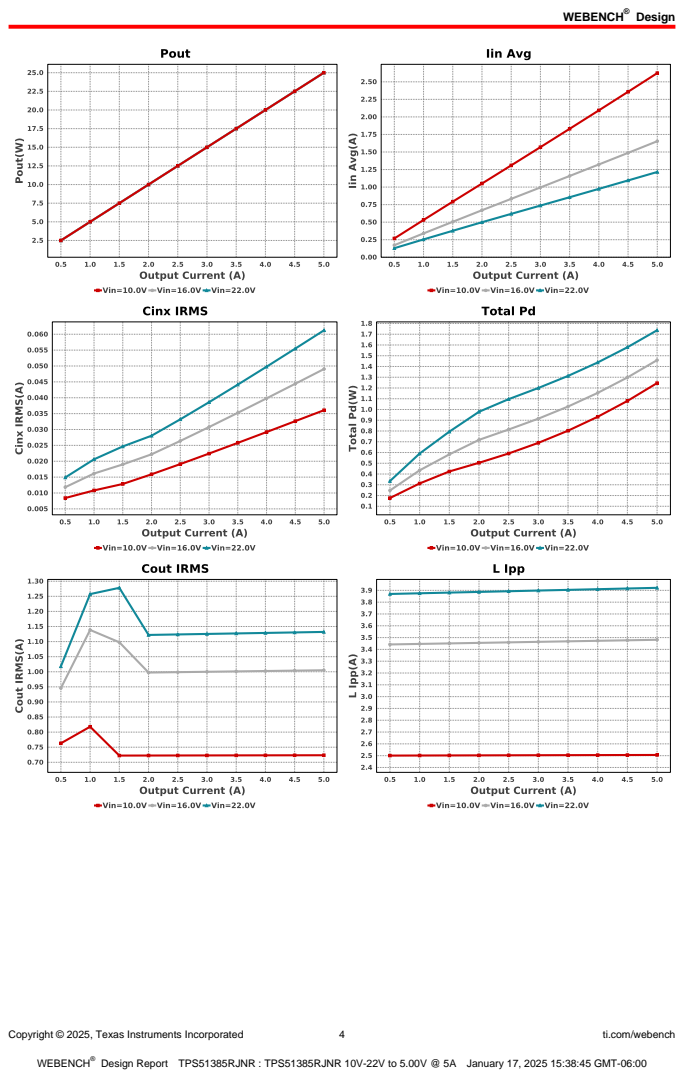
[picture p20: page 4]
Copyright © 2025, Texas Instruments Incorporated; ti.com/webench

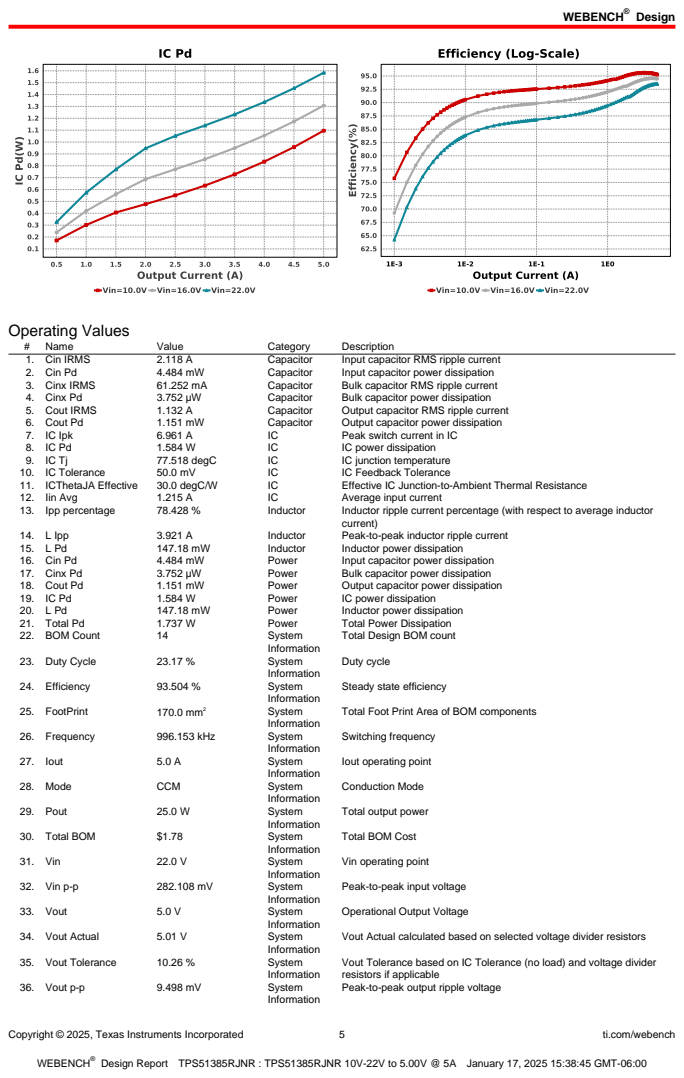
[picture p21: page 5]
Copyright © 2025, Texas Instruments Incorporated; ti.com/webench; Operating Values; Name; Value; Category; Description; 1. Cin IRMS; Capacitor; Input capacitor RMS ripple current; 2. Cin Pd; Input capacitor power dissipation; 3. Cinx IRMS; Bulk capacitor RMS ripple current; 4. Cinx Pd; Bulk capacitor power dissipation; 5. Cout IRMS; Output capacitor RMS ripple current; 6. Cout Pd; Output capacitor power dissipation; 7. IC Ipk; Peak switch current in IC; IC power dissipation; 77.518 degC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

Total Design BOM count

Steady state efficiency

Total Foot Print Area of BOM components

Iout operating point

Total output power

Total BOM Cost

Vin operating point

Peak-to-peak input voltage

Operational Output Voltage

Vout Actual calculated based on selected voltage divider resistors

Vout Tolerance based on IC Tolerance (no load) and voltage divider
resistors if applicable
Peak-to-peak output ripple voltage

Copyright © 2025, Texas Instruments Incorporated | 6 | ti.com/webench
# | Name | Value | Category | Description

37. SoftStart Time Actual 0.0 s | Softstart Time (Calculated)

## Design Inputs

Name | Value | Description
Iout | 5.0 | Maximum Output Current
VinMax | 22.0 | Maximum input voltage
VinMin | 10.0 | Minimum input voltage
Vout | 5.0 | Output Voltage
| base_pn | | TPS51385 | Base Product Number
source | DC | Input Source Type
Ta | 30.0 | Ambient temperature


Copyright © 2025, Texas Instruments Incorporated | 7 | ti.com/webench

## Assembly

## Component Testing

Some published data on components in datasheets such as Capacitor ESR and Inductor DC resistance is based on conservative values that will guarantee that the components always exceed the specification. For design purposes it is usually better to work with typical values. Since this data is not always available it is a good practice to measure the Capacitance and ESR values of Cin and Cout, and the inductance and DC resistance of L1 before assembly of the board. Any large discrepancies in values should be electrically simulated in WEBENCH to check for instabilities and thermally simulated in WebTHERM to make sure critical temperatures are not exceeded.

## Soldering Component to Board

If board assembly is done in house it is best to tack down one terminal of a component on the board then solder the other terminal. For surface mount parts with large tabs, such as the DPAK, the tab on the back of the package should be pre-tinned with solder, then tacked into place by one of the pins. To solder the tab town to the board place the iron down on the board while resting against the tab, heating both surfaces simultaneously. Apply light pressure to the top of the plastic case until the solder flows around the part and the part is flush with the PCB. If the solder is not flowing around the board you may need a higher wattage iron (generally 25W to 30W is enough).
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

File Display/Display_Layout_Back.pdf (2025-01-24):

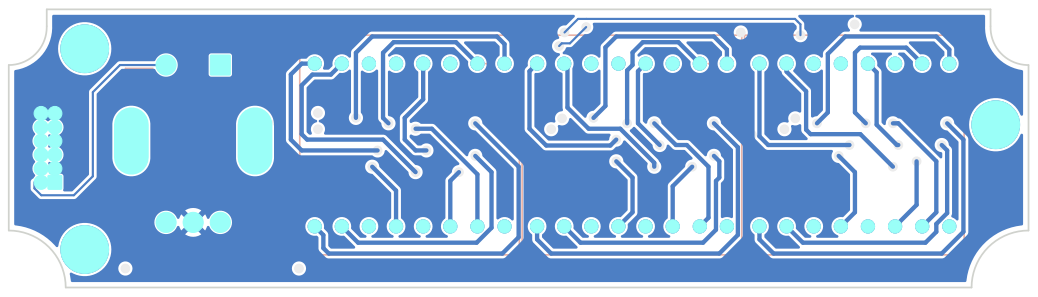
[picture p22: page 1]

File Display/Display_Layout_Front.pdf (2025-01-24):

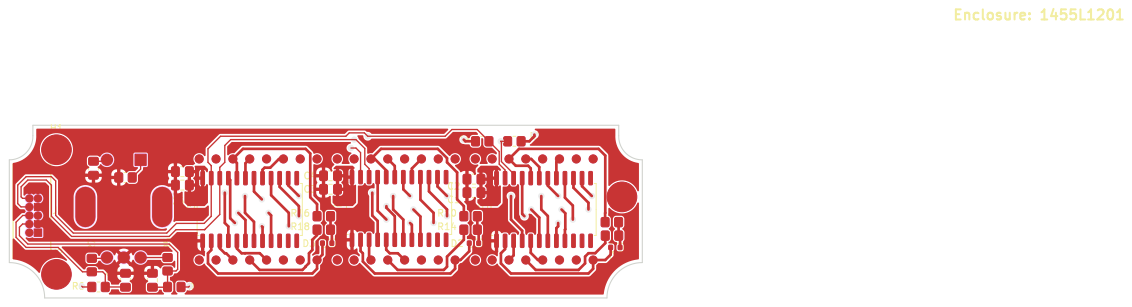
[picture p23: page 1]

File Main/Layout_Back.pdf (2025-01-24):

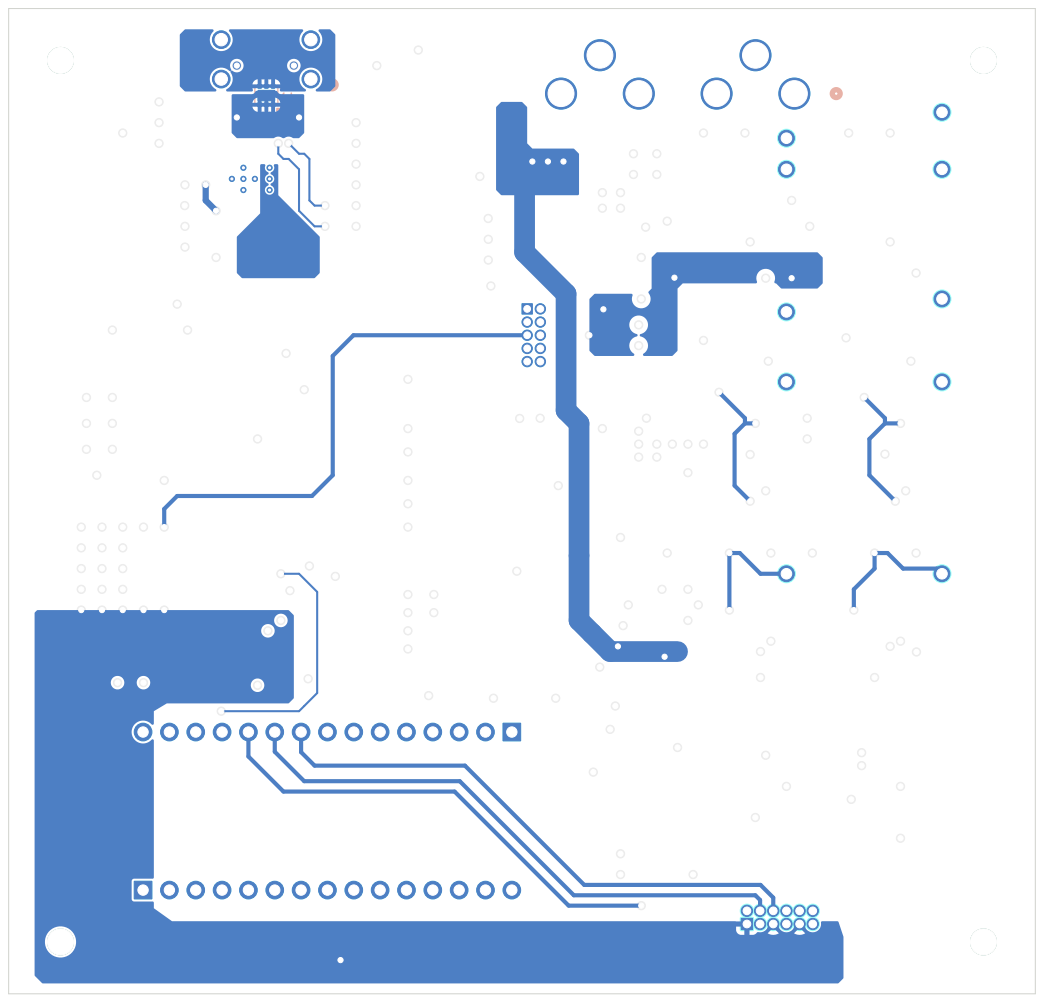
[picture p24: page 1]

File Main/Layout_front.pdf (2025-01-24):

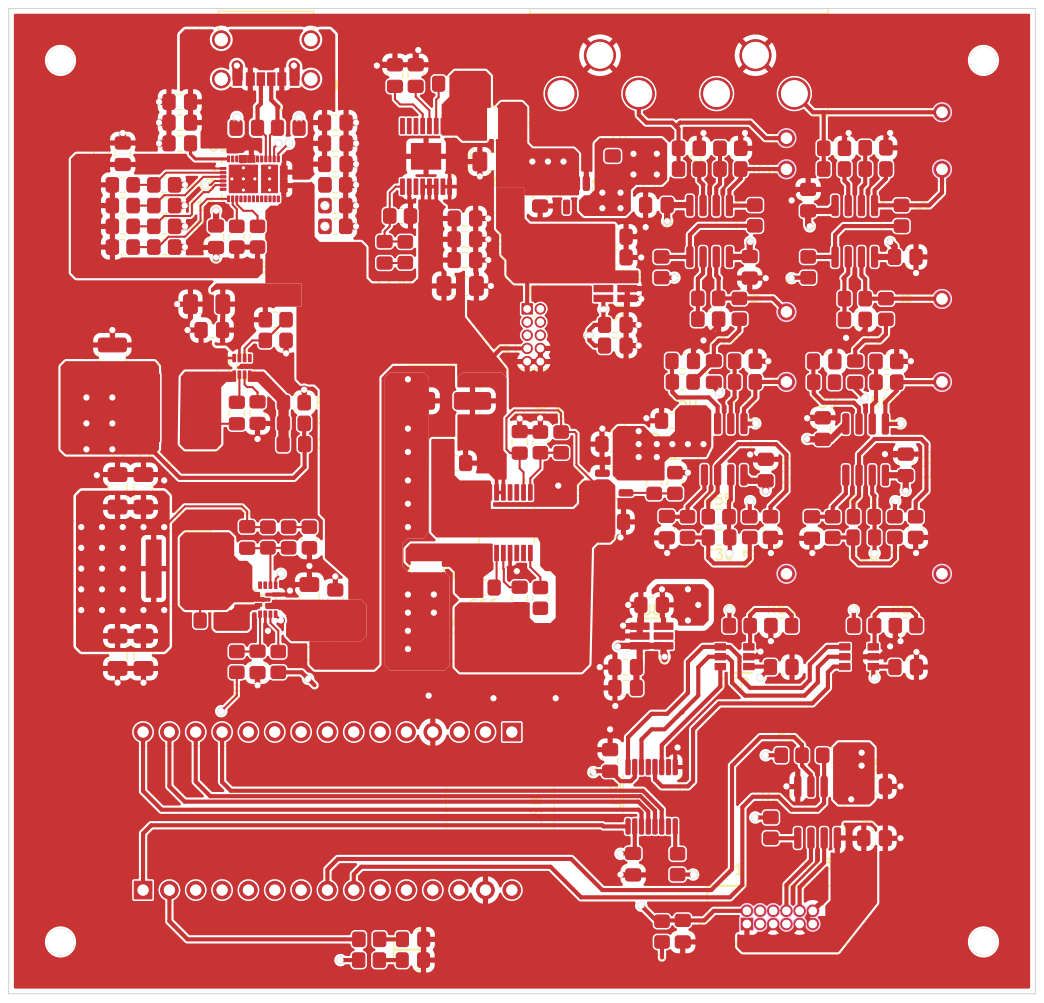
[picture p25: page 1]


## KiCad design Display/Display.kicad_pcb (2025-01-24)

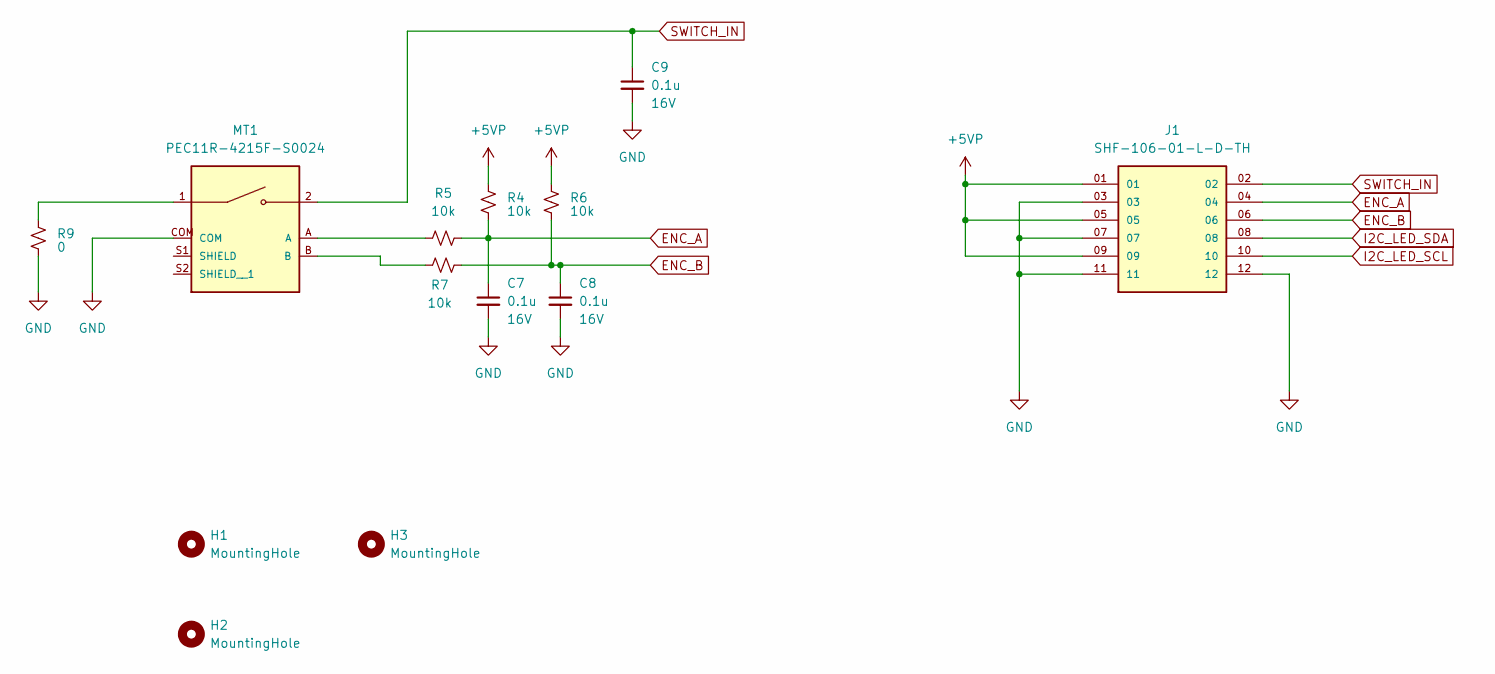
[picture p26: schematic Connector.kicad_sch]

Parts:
C7, C8, C9: 0.1u; C_0805_2012Metric_Pad1.18x1.45mm_HandSolder; Voltage 16V; Part Number 0805YC104MAT2A
H1, H2, H3: MountingHole; MountingHole_2.2mm_M2_Pad
J1: SHF-106-01-L-D-TH; SAMTEC_SHF-106-01-L-D-TH; PARTREV R
MT1: PEC11R-4215F-S0024; XDCR_PEC11R-4215F-S0024; PARTREV Rev. 09/19
R4, R5, R6, R7: 10k; R_0805_2012Metric_Pad1.20x1.40mm_HandSolder; Part Number CRCW080510K0FKEA
R9: 0; R_0805_2012Metric_Pad1.20x1.40mm_HandSolder; Part Number CRCW08050000FKEA

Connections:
+5VP: J1.01, J1.05, J1.09, R4.1, R6.1; also elsewhere on the board
ENC_A: C7.1, J1.04, R4.2, R5.2
ENC_B: C8.1, J1.06, R6.2, R7.2
GND: C7.2, C8.2, C9.2, J1.03, J1.07, J1.11, J1.12, MT1.COM, R9.2; also elsewhere on the board
I2C_LED_SCL: J1.10; also elsewhere on the board
I2C_LED_SDA: J1.08; also elsewhere on the board
unnamed: MT1.1, R9.1
unnamed: MT1.A, R5.1
unnamed: MT1.B, R7.1
SWITCH_IN: C9.1, J1.02, MT1.2

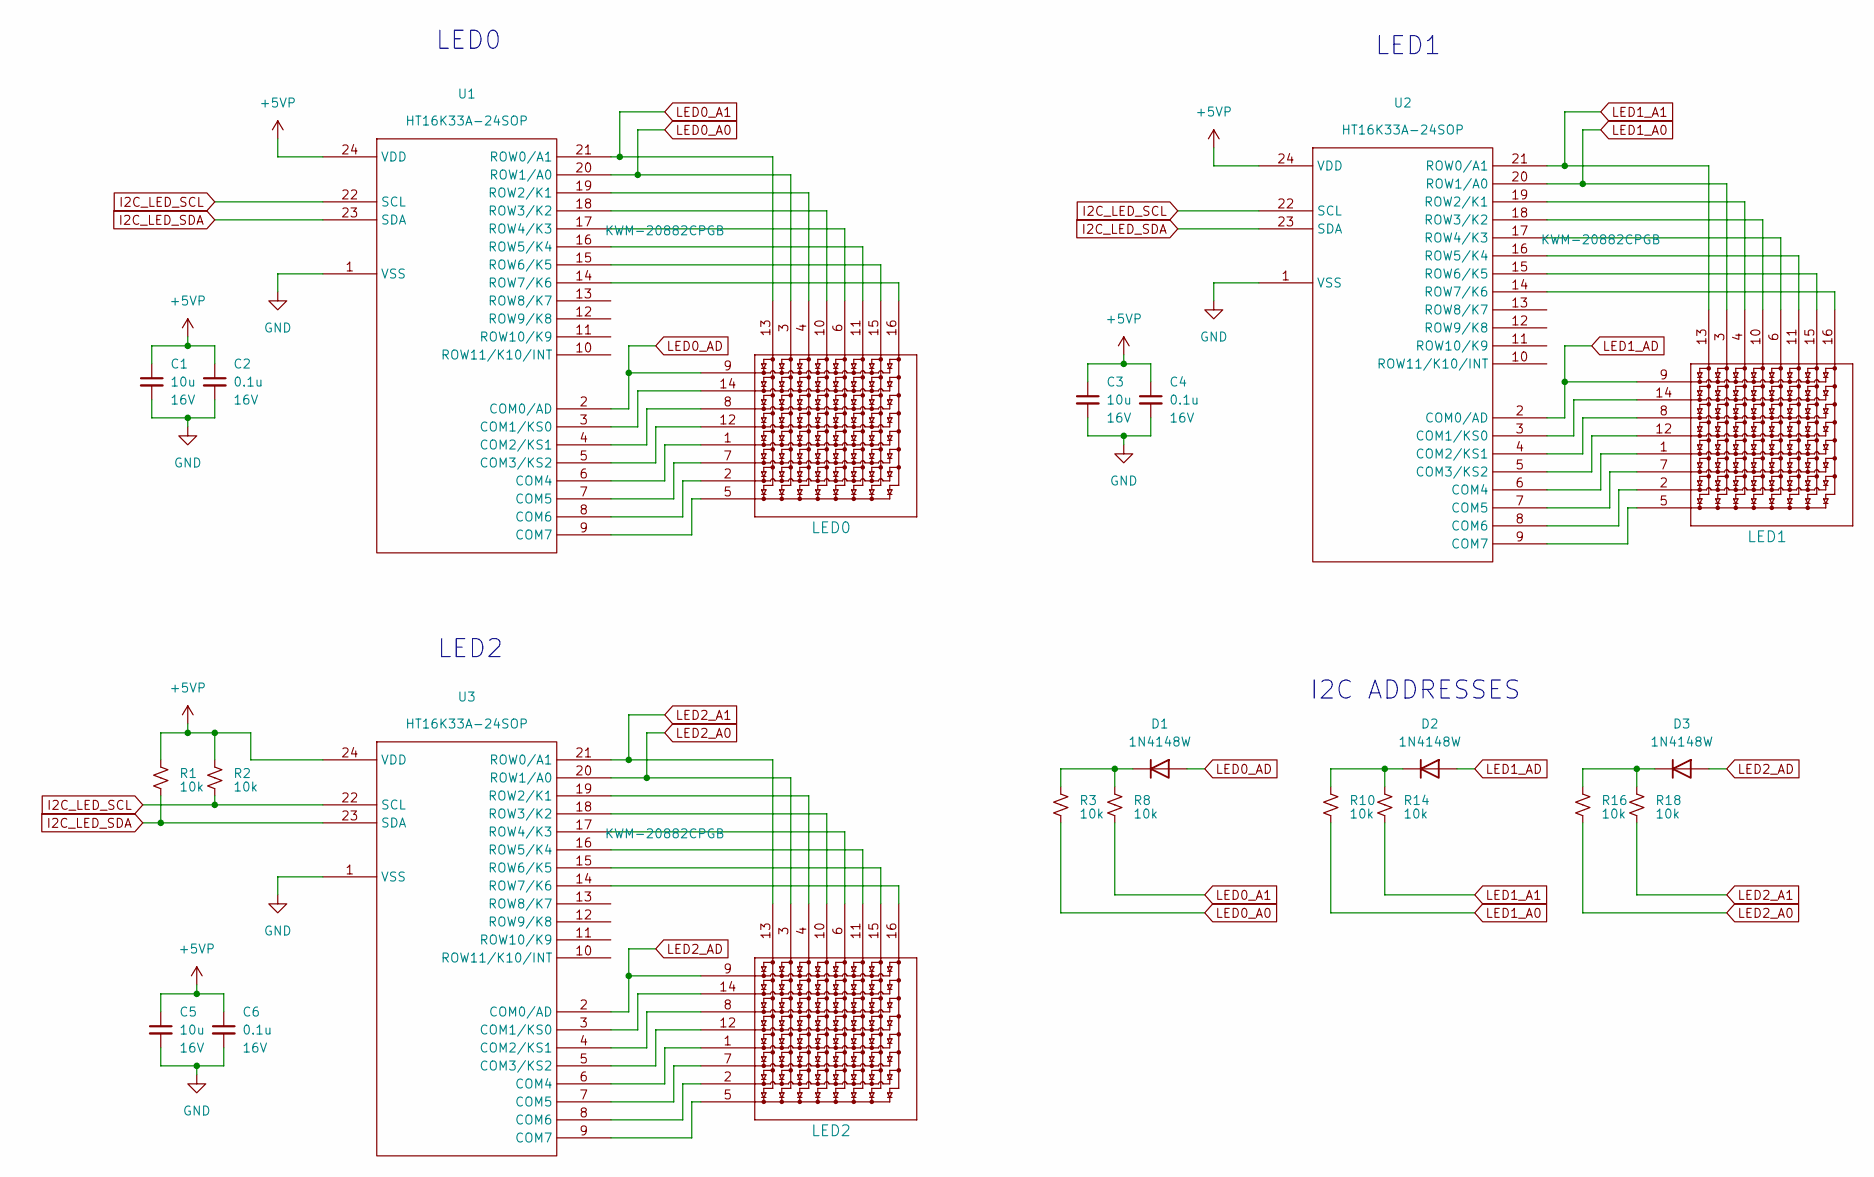
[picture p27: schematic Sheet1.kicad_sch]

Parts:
C1, C3, C5: 10u; C_0805_2012Metric_Pad1.18x1.45mm_HandSolder; Voltage 16V; Part Number 0805YC106MAT2A
C2, C4, C6: 0.1u; C_0805_2012Metric_Pad1.18x1.45mm_HandSolder; Voltage 16V; Part Number 0805YC104MAT2A
D1, D2: 1N4148W; D_SOD-523
D3: 1N4148W; D_SOD-523; Part Number 1N4148W
LED0, LED1, LED2: KWM-R30881CBB; KWM-20882AUGB; Part Number KWM-20882CPGB
R1, R2, R3, R8, R10, R14, R16, R18: 10k; R_0805_2012Metric_Pad1.20x1.40mm_HandSolder; Part Number CRCW080510K0FKEA
U1, U2, U3: SOP-24_7.5x15.4mm_P1.27mm; Part Number HT16K33A-24SOP

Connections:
+5VP: C1.1, C2.1, C3.1, C4.1, C5.1, C6.1, R1.1, R2.1, U1.24 (VDD), U2.24 (VDD), U3.24 (VDD); also elsewhere on the board
GND: C1.2, C2.2, C3.2, C4.2, C5.2, C6.2, U1.1 (VSS), U2.1 (VSS), U3.1 (VSS); also elsewhere on the board
I2C_LED_SCL: R2.2, U1.22 (SCL), U2.22 (SCL), U3.22 (SCL); also elsewhere on the board
I2C_LED_SDA: R1.2, U1.23 (SDA), U2.23 (SDA), U3.23 (SDA); also elsewhere on the board
LED0_A0: LED0.3 (ANODE_2), R3.2, U1.20 (ROW1/A0)
LED0_A1: LED0.13 (ANODE_1), R8.2, U1.21 (ROW0/A1)
LED0_AD: D1.2 (A), LED0.9 (CATHODE_1), U1.2 (COM0/AD)
LED1_A0: LED1.3 (ANODE_2), R10.2, U2.20 (ROW1/A0)
LED1_A1: LED1.13 (ANODE_1), R14.2, U2.21 (ROW0/A1)
LED1_AD: D2.2 (A), LED1.9 (CATHODE_1), U2.2 (COM0/AD)
LED2_A0: LED2.3 (ANODE_2), R16.2, U3.20 (ROW1/A0)
LED2_A1: LED2.13 (ANODE_1), R18.2, U3.21 (ROW0/A1)
LED2_AD: D3.2 (A), LED2.9 (CATHODE_1), U3.2 (COM0/AD)
unnamed: D1.1 (K), R3.1, R8.1
unnamed: D2.1 (K), R10.1, R14.1
unnamed: D3.1 (K), R16.1, R18.1
unnamed: LED0.4 (ANODE_3), U1.19 (ROW2/K1)
unnamed: LED0.10 (ANODE_4), U1.18 (ROW3/K2)
unnamed: LED0.6 (ANODE_5), U1.17 (ROW4/K3)
unnamed: LED0.11 (ANODE_6), U1.16 (ROW5/K4)
unnamed: LED0.15 (ANODE_7), U1.15 (ROW6/K5)
unnamed: LED0.16 (ANODE_8), U1.14 (ROW7/K6)
unnamed: LED0.14 (CATHODE_2), U1.3 (COM1/KS0)
unnamed: LED0.8 (CATHODE_3), U1.4 (COM2/KS1)
unnamed: LED0.12 (CATHODE_4), U1.5 (COM3/KS2)
unnamed: LED0.1 (CATHODE_5), U1.6 (COM4)
unnamed: LED0.7 (CATHODE_6), U1.7 (COM5)
unnamed: LED0.2 (CATHODE_7), U1.8 (COM6)
unnamed: LED0.5 (CATHODE_8), U1.9 (COM7)
unnamed: LED1.4 (ANODE_3), U2.19 (ROW2/K1)
unnamed: LED1.10 (ANODE_4), U2.18 (ROW3/K2)
unnamed: LED1.6 (ANODE_5), U2.17 (ROW4/K3)
unnamed: LED1.11 (ANODE_6), U2.16 (ROW5/K4)
unnamed: LED1.15 (ANODE_7), U2.15 (ROW6/K5)
unnamed: LED1.16 (ANODE_8), U2.14 (ROW7/K6)
unnamed: LED1.14 (CATHODE_2), U2.3 (COM1/KS0)
unnamed: LED1.8 (CATHODE_3), U2.4 (COM2/KS1)
unnamed: LED1.12 (CATHODE_4), U2.5 (COM3/KS2)
unnamed: LED1.1 (CATHODE_5), U2.6 (COM4)
unnamed: LED1.7 (CATHODE_6), U2.7 (COM5)
unnamed: LED1.2 (CATHODE_7), U2.8 (COM6)
unnamed: LED1.5 (CATHODE_8), U2.9 (COM7)
unnamed: LED2.4 (ANODE_3), U3.19 (ROW2/K1)
unnamed: LED2.10 (ANODE_4), U3.18 (ROW3/K2)
unnamed: LED2.6 (ANODE_5), U3.17 (ROW4/K3)
unnamed: LED2.11 (ANODE_6), U3.16 (ROW5/K4)
unnamed: LED2.15 (ANODE_7), U3.15 (ROW6/K5)
unnamed: LED2.16 (ANODE_8), U3.14 (ROW7/K6)
unnamed: LED2.14 (CATHODE_2), U3.3 (COM1/KS0)
unnamed: LED2.8 (CATHODE_3), U3.4 (COM2/KS1)
unnamed: LED2.12 (CATHODE_4), U3.5 (COM3/KS2)
unnamed: LED2.1 (CATHODE_5), U3.6 (COM4)
unnamed: LED2.7 (CATHODE_6), U3.7 (COM5)
unnamed: LED2.2 (CATHODE_7), U3.8 (COM6)
unnamed: LED2.5 (CATHODE_8), U3.9 (COM7)

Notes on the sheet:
LED1
I2C ADDRESSES
LED0
LED2

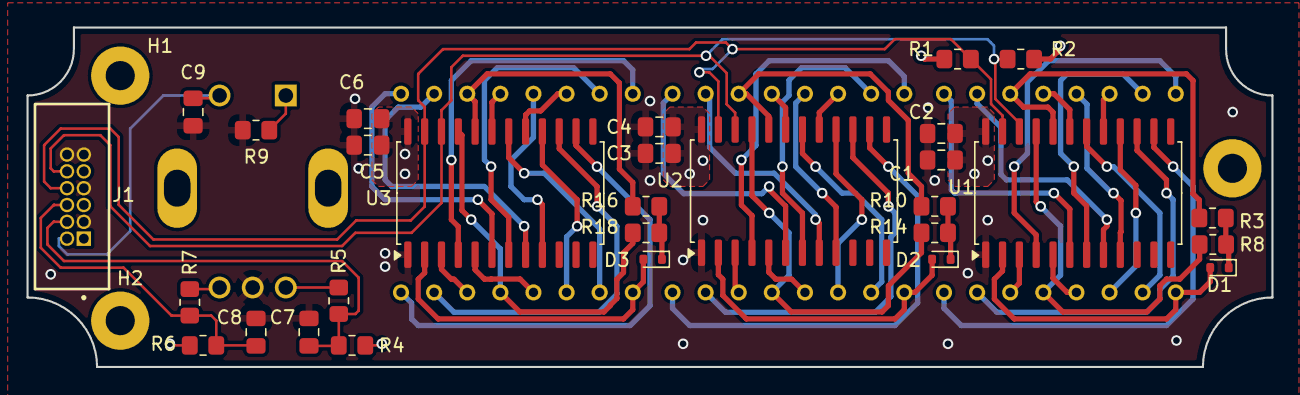
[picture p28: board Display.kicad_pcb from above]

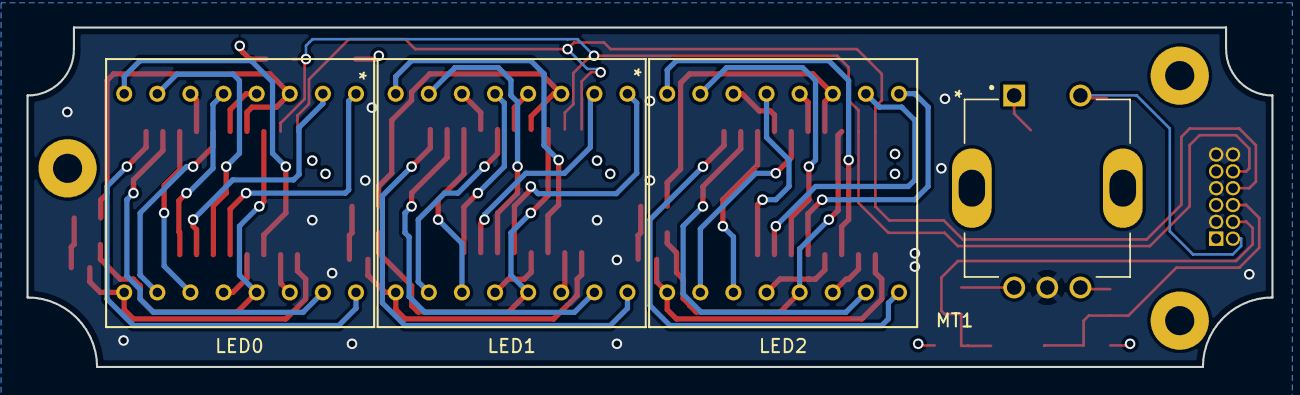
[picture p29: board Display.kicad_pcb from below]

Board: 4 copper layers, 94.0 x 25.6 mm, 36 parts (4 on the bottom side), 61 nets.

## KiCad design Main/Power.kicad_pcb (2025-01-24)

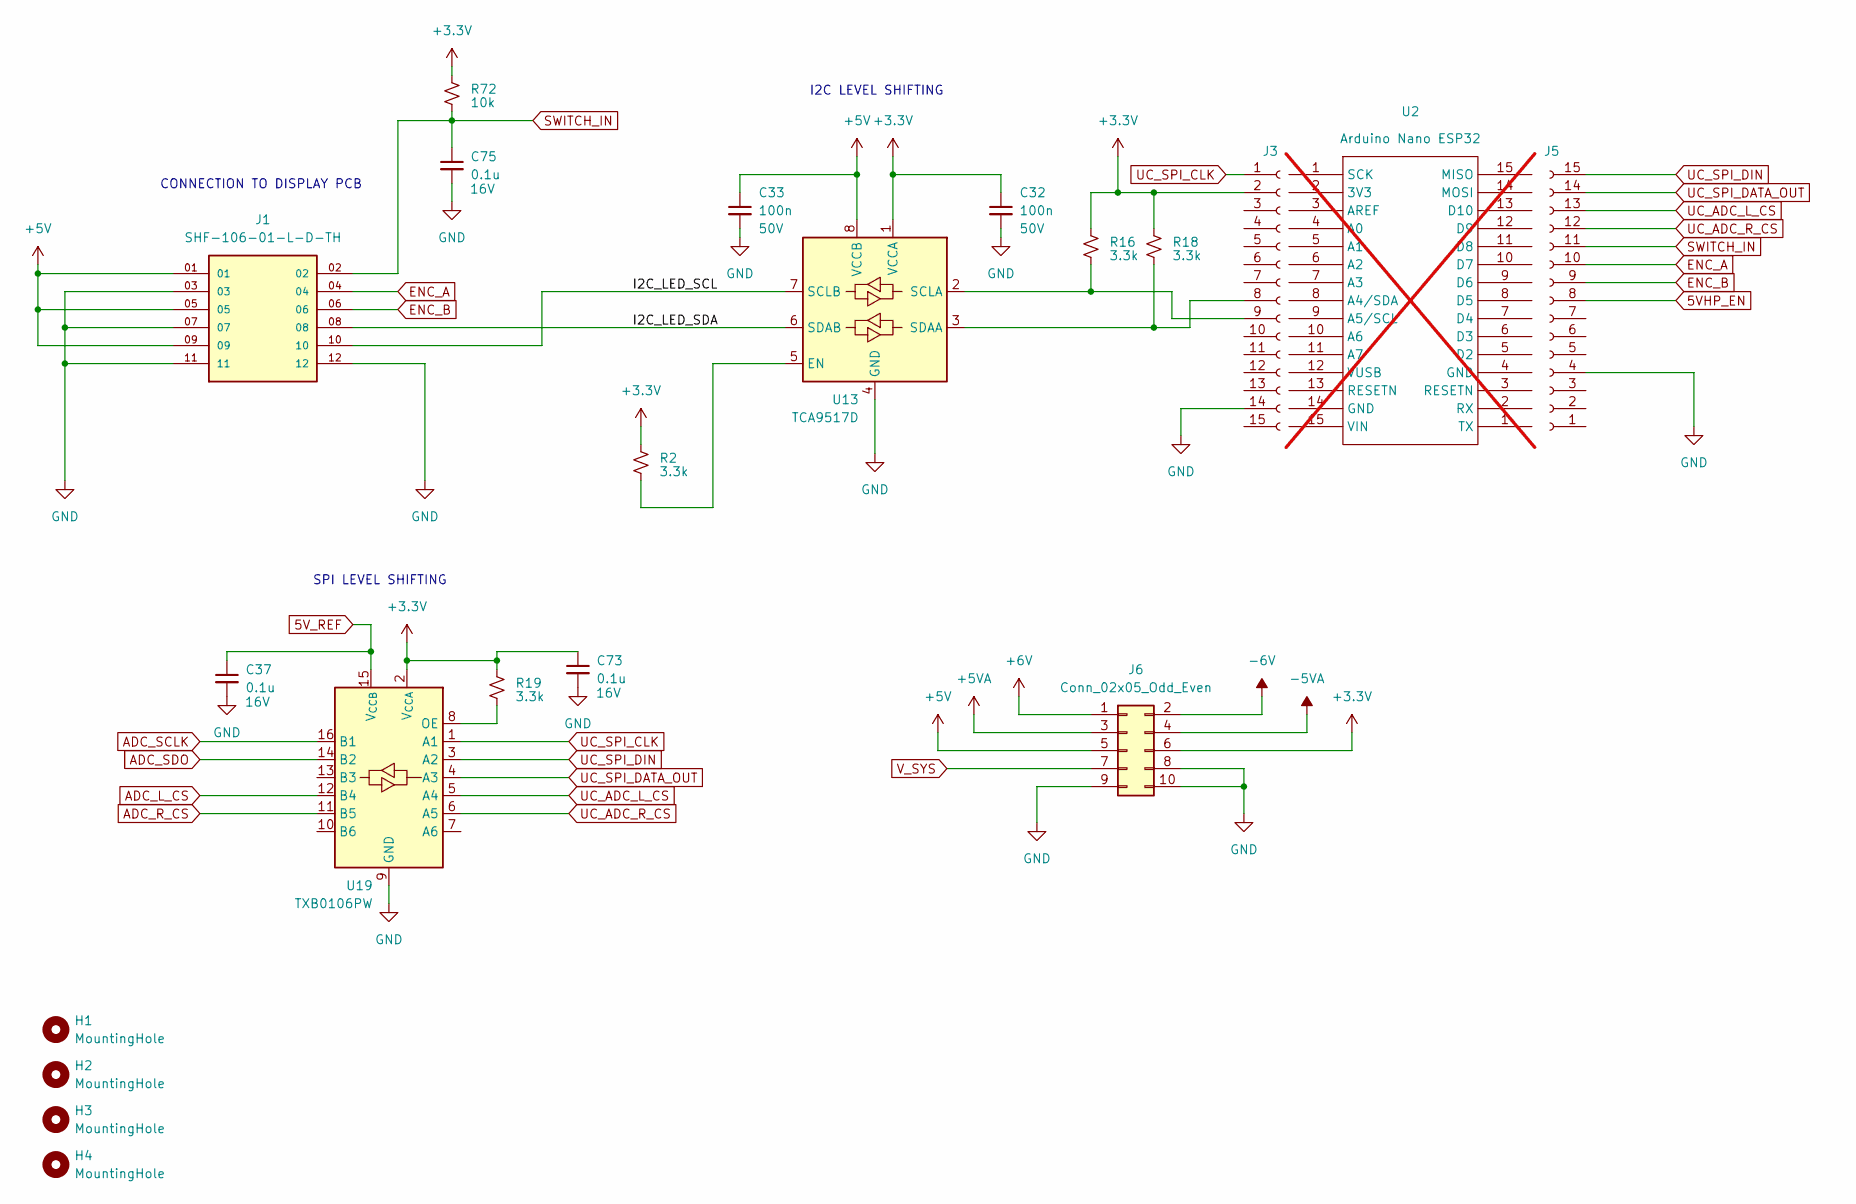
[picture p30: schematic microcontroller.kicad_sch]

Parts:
C32, C33: 100n; C_0805_2012Metric_Pad1.18x1.45mm_HandSolder; Voltage 50V; Part Number GRM21BR71H104KA01L
C37, C73, C75: 0.1u; C_0805_2012Metric_Pad1.18x1.45mm_HandSolder; Voltage 16V; Part Number 0805YC104MAT2A
H1, H2, H3, H4: MountingHole; MountingHole_2.5mm
J1: SHF-106-01-L-D-TH; SAMTEC_SHF-106-01-L-D-TH; PARTREV R
J3, J5: Conn_01x15_Socket; PinSocket_1x15_P2.54mm_Vertical
J6: Conn_02x05_Odd_Even; PinHeader_2x05_P1.27mm_Vertical
R2, R16, R18, R19: 3.3k; R_0805_2012Metric_HandSolder; Part Number CRCW08053K30FKEA
R72: 10k; R_0805_2012Metric_HandSolder
U2: Arduino_Nano_WithMountingHoles; Part Number Arduino Nano ESP32; not fitted
U13: TCA9517D; SOIC-8_3.9x4.9mm_P1.27mm; Part Number TCA9517D
U19: TXB0106PW; TSSOP-16_4.4x5mm_P0.65mm; Part Number TXB0106PW

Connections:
5VHP_EN: J5.8; also elsewhere on the board
5V_REF: C37.1, U19.15 (V_{CCB}); also elsewhere on the board
+3.3V: C32.1, C73.1, J3.2, J6.6, R2.2, R16.2, R18.2, R19.2, R72.2, U13.1 (VCCA), U19.2 (V_{CCA}); also elsewhere on the board
+5V: C33.1, J1.01, J1.05, J1.09, J6.5, U13.8 (VCCB); also elsewhere on the board
+5VA: J6.3; also elsewhere on the board
+6V: J6.1; also elsewhere on the board
-5VA: J6.4; also elsewhere on the board
-6V: J6.2; also elsewhere on the board
/Microcontroller/I2C_LED_SCL: J1.10, U13.7 (SCLB)
/Microcontroller/I2C_LED_SDA: J1.08, U13.6 (SDAB)
ADC_L_CS: U19.12 (B4); also elsewhere on the board
ADC_R_CS: U19.11 (B5); also elsewhere on the board
ADC_SCLK: U19.16 (B1); also elsewhere on the board
ADC_SDO: U19.14 (B2); also elsewhere on the board
ENC_A: J1.04, J5.10
ENC_B: J1.06, J5.9
GND: C32.2, C33.2, C37.2, C73.2, C75.2, J1.03, J1.07, J1.11, J1.12, J3.14, J5.4, J6.8, J6.9, J6.10, U13.4 (GND), U19.9 (GND); also elsewhere on the board
unnamed: J3.8, R18.1, U13.3 (SDAA)
unnamed: J3.9, R16.1, U13.2 (SCLA)
unnamed: R2.1, U13.5 (EN)
unnamed: R19.1, U19.8 (OE)
SWITCH_IN: C75.1, J1.02, J5.11, R72.1
UC_ADC_L_CS: J5.13, U19.5 (A4)
UC_ADC_R_CS: J5.12, U19.6 (A5)
UC_SPI_CLK: J3.1, U19.1 (A1)
UC_SPI_DATA_OUT: J5.14, U19.4 (A3)
UC_SPI_DIN: J5.15, U19.3 (A2)
V_SYS: J6.7; also elsewhere on the board

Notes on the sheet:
SPI LEVEL SHIFTING
CONNECTION TO DISPLAY PCB
I2C LEVEL SHIFTING

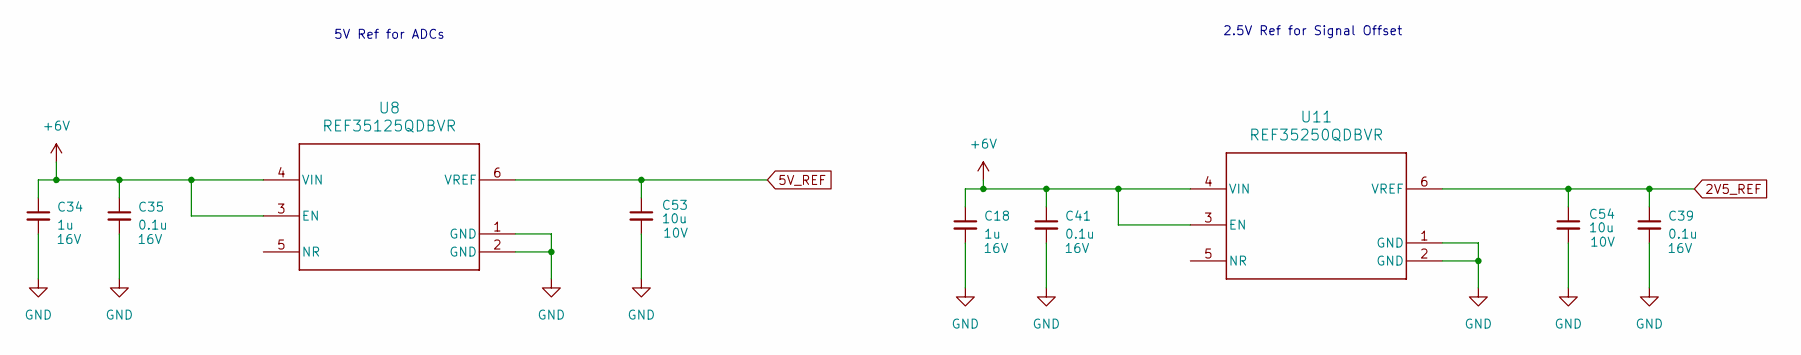
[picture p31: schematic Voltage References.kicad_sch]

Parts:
C18, C34: 1u; C_0805_2012Metric_Pad1.18x1.45mm_HandSolder; Voltage 16V; Part Number 0805YC105KAT2A
C35, C39, C41: 0.1u; C_0805_2012Metric_Pad1.18x1.45mm_HandSolder; Voltage 16V; Part Number 0805YC104MAT2A
C53, C54: 10u; C_0805_2012Metric_Pad1.18x1.45mm_HandSolder; Voltage 10V; Part Number MBASL21GBB7106KTNA18
U8: REF35125QDBVR; DBV0006A-IPC_A; Part Number REF35125QDBVR
U11: REF35250QDBVR; DBV0006A-IPC_A; Part Number REF35250QDBVR

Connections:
2V5_REF: C39.1, C54.1, U11.6 (VREF); also elsewhere on the board
5V_REF: C53.1, U8.6 (VREF); also elsewhere on the board
+6V: C18.1, C34.1, C35.1, C41.1, U8.3 (EN), U8.4 (VIN), U11.3 (EN), U11.4 (VIN); also elsewhere on the board
GND: C18.2, C34.2, C35.2, C39.2, C41.2, C53.2, C54.2, U8.1 (GND), U8.2 (GND), U11.1 (GND), U11.2 (GND); also elsewhere on the board

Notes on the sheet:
2.5V Ref for Signal Offset
5V Ref for ADCs

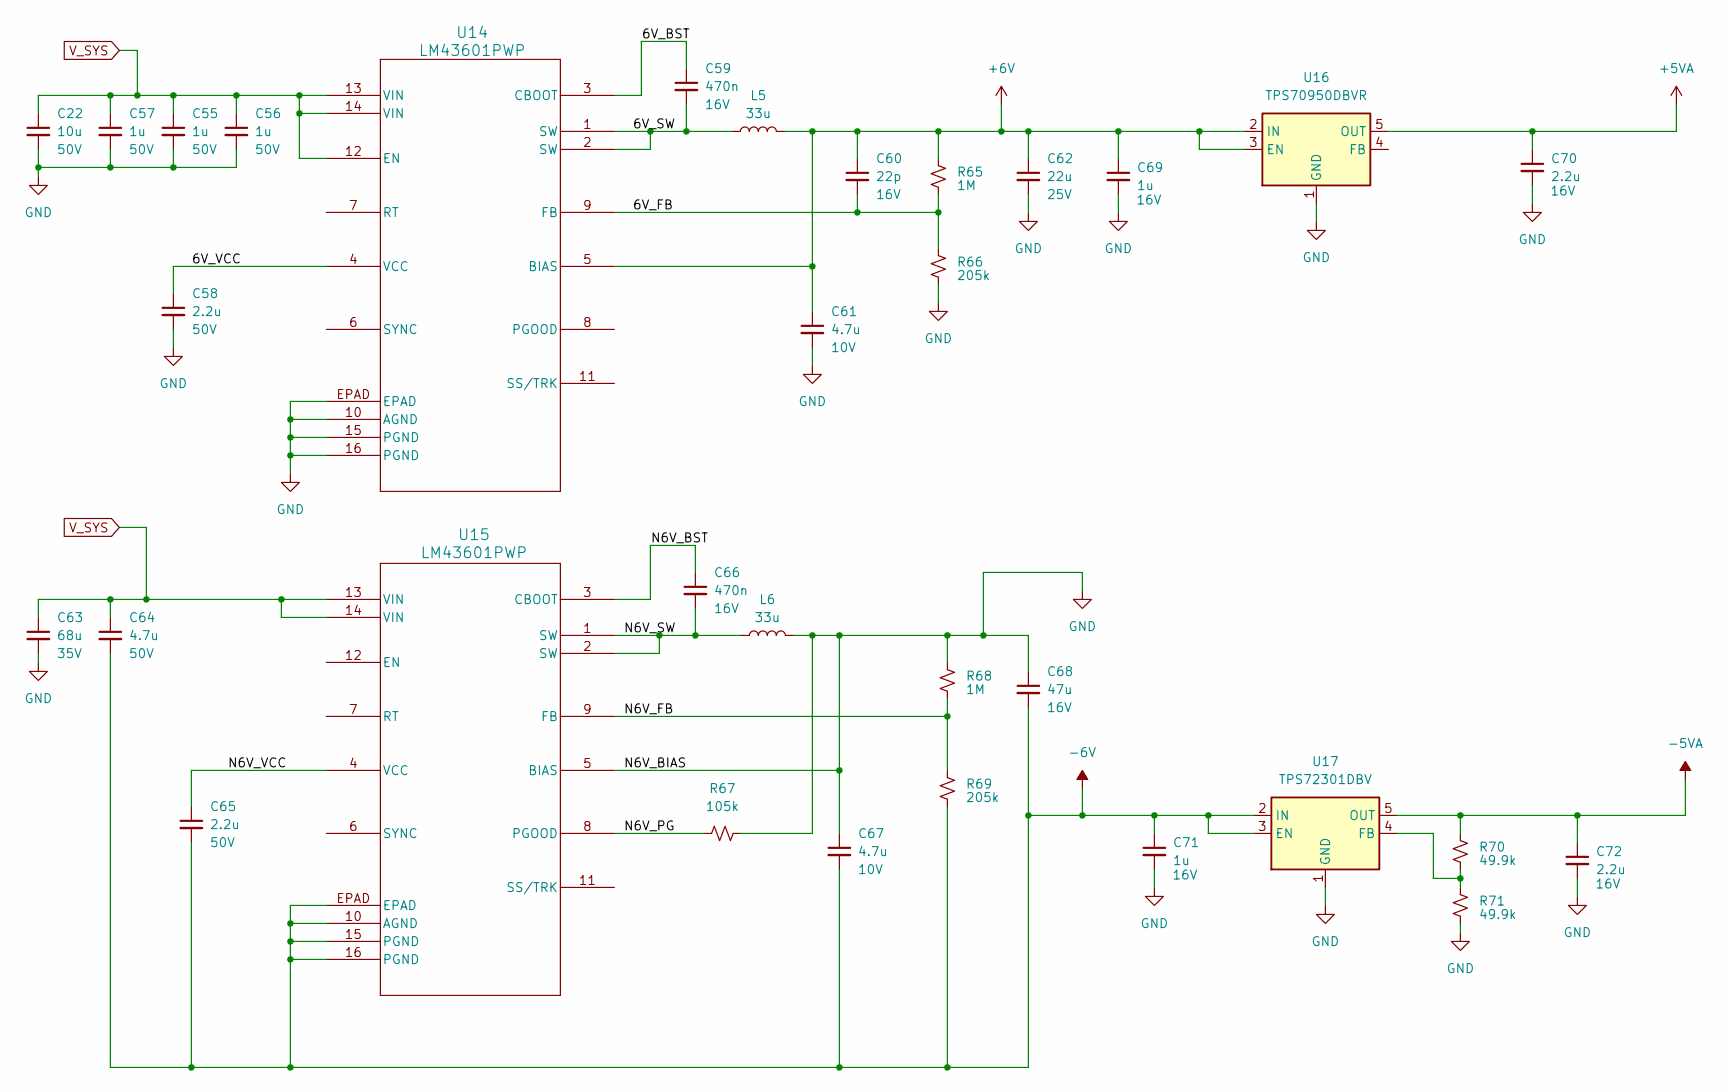
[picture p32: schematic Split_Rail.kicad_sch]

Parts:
C22: 10u; C_1206_3216Metric_Pad1.33x1.80mm_HandSolder; Voltage 50V; Part Number C3216X5R1H106K160AB
C55, C56, C57: 1u; C_0805_2012Metric_Pad1.18x1.45mm_HandSolder; Voltage 50V; Part Number 08055C105K4Z4A
C58, C65: 2.2u; C_0805_2012Metric_Pad1.18x1.45mm_HandSolder; Voltage 50V; Part Number 08055C225MAT2A
C59, C66: 470n; C_0805_2012Metric_Pad1.18x1.45mm_HandSolder; Voltage 16V; Part Number 0805YC474MAT2A
C60: 22p; C_0805_2012Metric_Pad1.18x1.45mm_HandSolder; Voltage 16V; Part Number 0805YA220JAT2A
C61, C67: 4.7u; C_0805_2012Metric_Pad1.18x1.45mm_HandSolder; Voltage 10V; Part Number LMK212B7475KG-T
C62: 22u; C_1206_3216Metric_Pad1.33x1.80mm_HandSolder; Voltage 25V; Part Number 12063D226KAT2A
C63: 68u; CP_Elec_6.3x7.7; Voltage 35V; Part Number UUD1V680MCL1GS
C64: 4.7u; C_0805_2012Metric_Pad1.18x1.45mm_HandSolder; Voltage 50V; Part Number C2012X5R1H475K125AB
C68: 47u; C_1210_3225Metric_Pad1.33x2.70mm_HandSolder; Voltage 16V; Part Number GRM32ER61C476KE15L
C69, C71: 1u; C_0805_2012Metric_Pad1.18x1.45mm_HandSolder; Voltage 16V; Part Number 0805YC105KAT2A
C70, C72: 2.2u; C_0805_2012Metric_Pad1.18x1.45mm_HandSolder; Voltage 16V; Part Number 0805YC225MAT2A
L5, L6: 33u; IND_BOURNS_SRN3015; Part Number SRN3015-330M
R65, R68: 1M; R_0805_2012Metric_Pad1.20x1.40mm_HandSolder
R66, R69: 205k; R_0805_2012Metric_Pad1.20x1.40mm_HandSolder
R67: 105k; R_0805_2012Metric_Pad1.20x1.40mm_HandSolder
R70, R71: 49.9k; R_0805_2012Metric_HandSolder
U14, U15: LM43601PWP; PWP16_TEX; Part Number LM43601PWP
U16: TPS70950DBVR; SOT-23-5; Part Number TPS70950DBVR
U17: TPS72301DBV; SOT-23-5; Part Number TPS72301DBV

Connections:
+5VA: C70.1, U16.5 (OUT); also elsewhere on the board
+6V: C60.1, C61.1, C62.1, C69.1, L5.2, R65.1, U14.5 (BIAS), U16.2 (IN), U16.3 (EN); also elsewhere on the board
-5VA: C72.1, R70.1, U17.5 (OUT); also elsewhere on the board
-6V: C64.2, C65.2, C67.2, C68.2, C71.1, R69.2, U15.10 (AGND), U15.15 (PGND), U15.16 (PGND), U15.EPAD, U17.2 (IN), U17.3 (EN); also elsewhere on the board
/Split Rail/6V_BST: C59.1, U14.3 (CBOOT)
/Split Rail/6V_FB: C60.2, R65.2, R66.1, U14.9 (FB)
/Split Rail/6V_SW: C59.2, L5.1, U14.1 (SW), U14.2 (SW)
/Split Rail/6V_VCC: C58.1, U14.4 (VCC)
/Split Rail/N6V_BST: C66.1, U15.3 (CBOOT)
/Split Rail/N6V_FB: R68.2, R69.1, U15.9 (FB)
/Split Rail/N6V_PG: R67.1, U15.8 (PGOOD)
/Split Rail/N6V_SW: C66.2, L6.1, U15.1 (SW), U15.2 (SW)
/Split Rail/N6V_VCC: C65.1, U15.4 (VCC)
GND: C22.2, C55.2, C56.2, C57.2, C58.2, C61.2, C62.2, C63.2, C67.1, C68.1, C69.2, C70.2, C71.2, C72.2, L6.2, R66.2, R67.2, R68.1, R71.2, U14.10 (AGND), U14.15 (PGND), U14.16 (PGND), U14.EPAD, U15.5 (BIAS), U16.1 (GND), U17.1 (GND); also elsewhere on the board
unnamed: R70.2, R71.1, U17.4 (FB)
V_SYS: C22.1, C55.1, C56.1, C57.1, C63.1, C64.1, U14.12 (EN), U14.13 (VIN), U14.14 (VIN), U15.13 (VIN), U15.14 (VIN); also elsewhere on the board

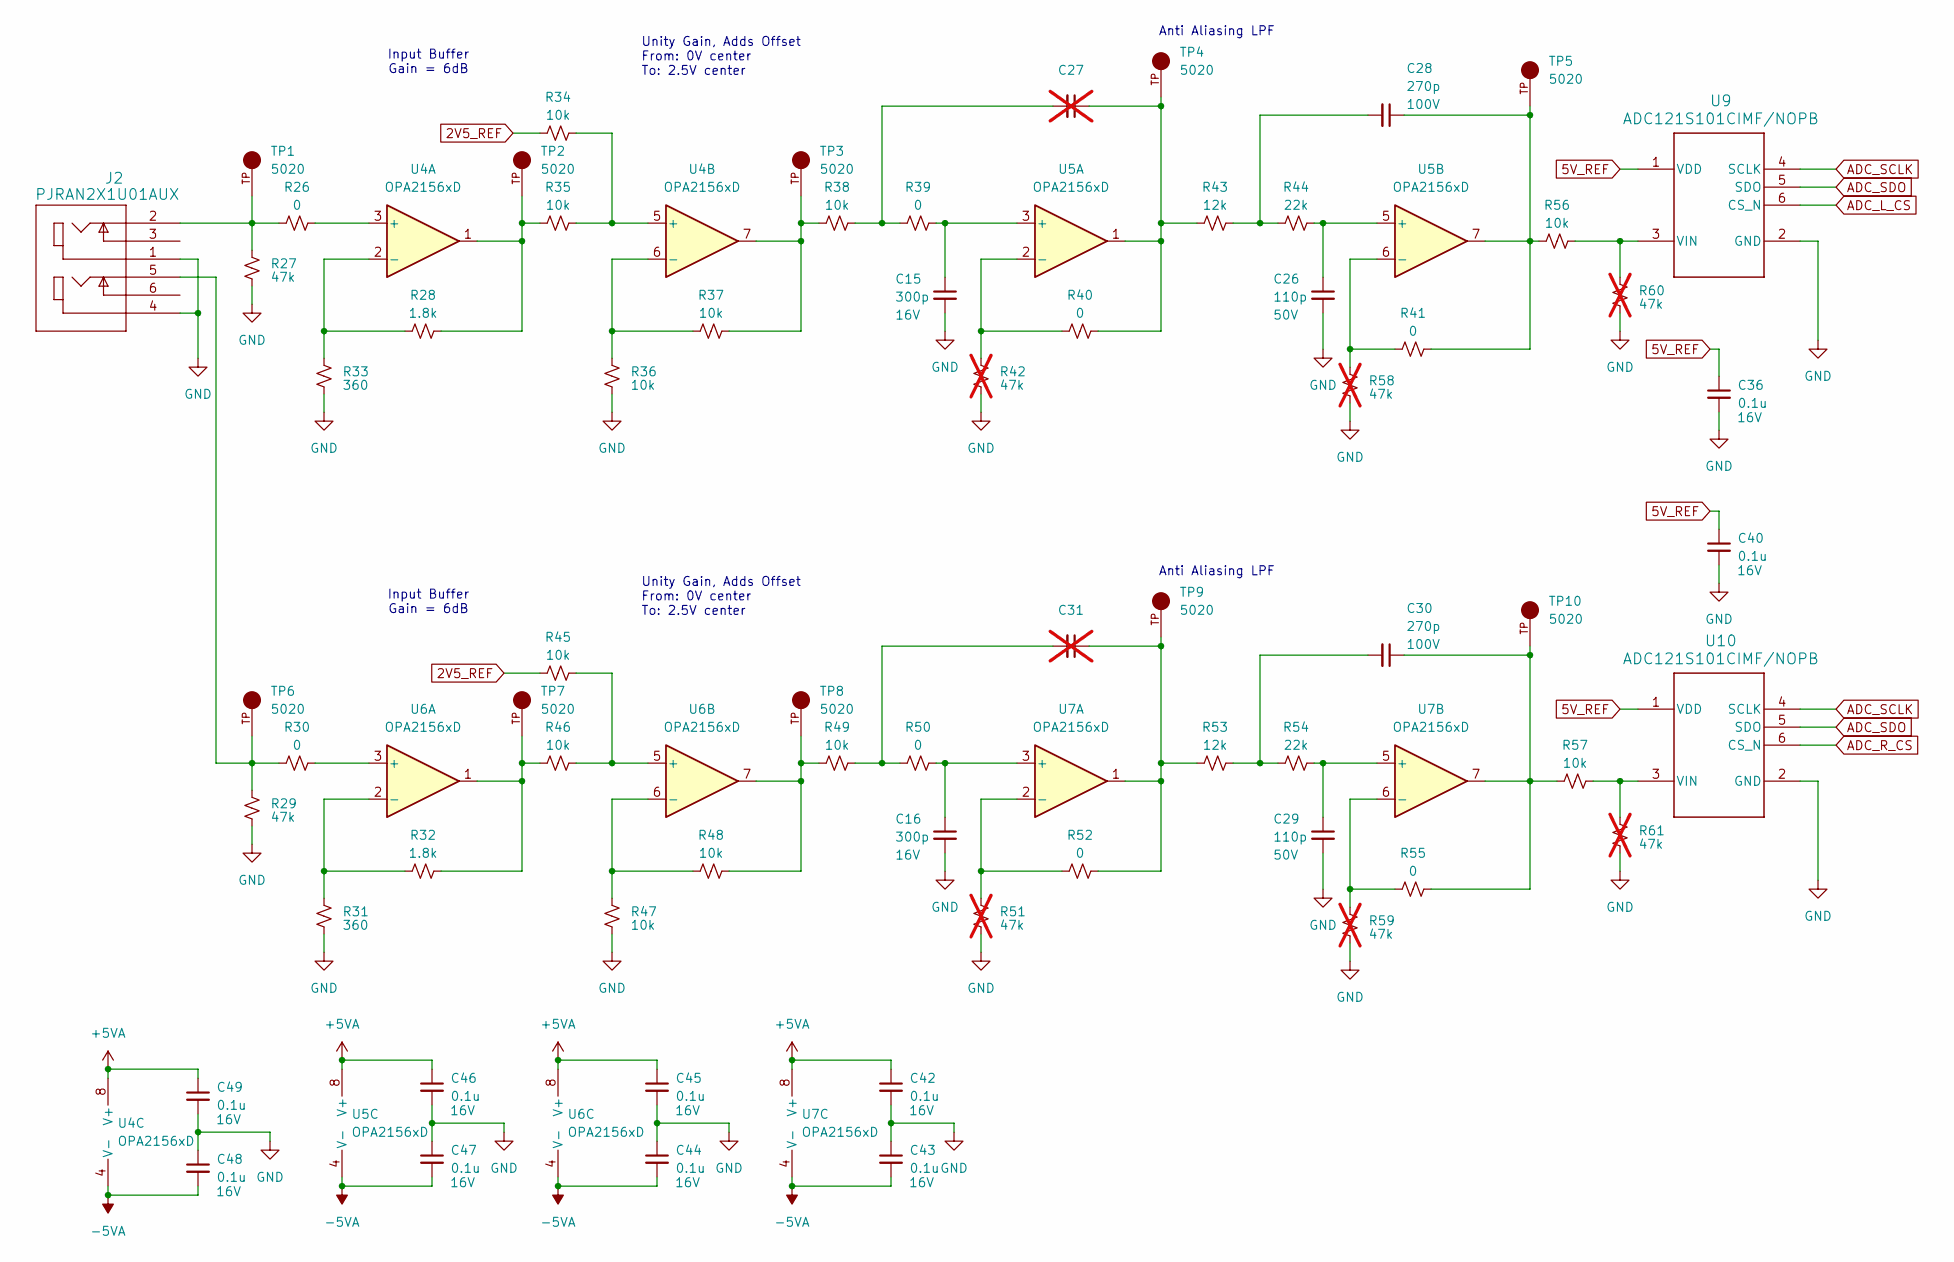
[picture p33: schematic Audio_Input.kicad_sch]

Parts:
C15, C16: 300p; C_0805_2012Metric_Pad1.18x1.45mm_HandSolder; Voltage 16V; Part Number 0805YC301JAT2A
C26, C29: 110p; C_0805_2012Metric_Pad1.18x1.45mm_HandSolder; Voltage 50V; Part Number 08055U111FAT2A
C27, C31: C_0805_2012Metric_Pad1.18x1.45mm_HandSolder; not fitted
C28, C30: 270p; C_0805_2012Metric_Pad1.18x1.45mm_HandSolder; Voltage 100V; Part Number 08051A271KAT2A
C36, C40, C42, C43, C44, C45, C46, C47, C48, C49: 0.1u; C_0805_2012Metric_Pad1.18x1.45mm_HandSolder; Voltage 16V; Part Number 0805YC104MAT2A
J2: PJRAN2X1U01AUX; CONN6_984x394_SWC_BS; Part Number PJRAN2X1U01AUX
R26, R30, R39, R40, R41, R50, R52, R55: 0; R_0805_2012Metric_HandSolder; Part Number CRCW08050000FKEA
R27, R29: 47k; R_0805_2012Metric_HandSolder; Part Number CRCW080547K0FKEA
R28, R32: 1.8k; R_0805_2012Metric_HandSolder; Part Number CRCW08051K80FKEA
R31, R33: 360; R_0805_2012Metric_HandSolder; Part Number CRCW0805360RFKEA
R34, R35, R36, R37, R38, R45, R46, R47, R48, R49, R56, R57: 10k; R_0805_2012Metric_HandSolder
R42, R51, R58, R59, R60, R61: 47k; R_0805_2012Metric_HandSolder; Part Number CRCW080547K0FKEA; not fitted
R43, R53: 12k; R_0805_2012Metric_HandSolder; Part Number CRCW080512K0FKEA
R44, R54: 22k; R_0805_2012Metric_HandSolder; Part Number CRCW080522K0FKEA
TP1, TP2, TP3, TP4, TP5, TP6, TP7, TP8, TP9, TP10: 5020; KEYSTONE_5020; PARTREV C
U4, U5, U6, U7: OPA2156xD; SOIC-8_3.9x4.9mm_P1.27mm; Part Number OPA2156xD
U9, U10: ADC121S101CIMF/NOPB; DBV0006A_N; Part Number ADC121S101CIMF/NOPB

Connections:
2V5_REF: R34.1, R45.1; also elsewhere on the board
5V_REF: C36.1, C40.1, U9.1 (VDD), U10.1 (VDD); also elsewhere on the board
+5VA: C42.1, C45.1, C46.1, C49.1, U4.8 (V+), U5.8 (V+), U6.8 (V+), U7.8 (V+); also elsewhere on the board
-5VA: C43.2, C44.2, C47.2, C48.2, U4.4 (V-), U5.4 (V-), U6.4 (V-), U7.4 (V-); also elsewhere on the board
ADC_L_CS: U9.6 (CS_N); also elsewhere on the board
ADC_R_CS: U10.6 (CS_N); also elsewhere on the board
ADC_SCLK: U9.4 (SCLK), U10.4 (SCLK); also elsewhere on the board
ADC_SDO: U9.5 (SDO), U10.5 (SDO); also elsewhere on the board
GND: C15.2, C16.2, C26.2, C29.2, C36.2, C40.2, C42.2, C43.1, C44.1, C45.2, C46.2, C47.1, C48.1, C49.2, J2.1, J2.4, R27.1, R29.1, R31.1, R33.1, R36.1, R42.1, R47.1, R51.1, R58.1, R59.1, R60.1, R61.1, U9.2 (GND), U10.2 (GND); also elsewhere on the board
unnamed: C27.1, R40.2, R43.1, TP4.TP, U5.1
unnamed: C27.2, R38.2, R39.1
unnamed: C28.1, R41.2, R56.1, TP5.TP, U5.7
unnamed: C28.2, R43.2, R44.1
unnamed: C30.1, R55.2, R57.1, TP10.TP, U7.7
unnamed: C30.2, R53.2, R54.1
unnamed: C31.1, R52.2, R53.1, TP9.TP, U7.1
unnamed: C31.2, R49.2, R50.1
unnamed: J2.2, R26.1, R27.2, TP1.TP
unnamed: J2.5, R29.2, R30.1, TP6.TP
unnamed: R28.2, R35.1, TP2.TP, U4.1
unnamed: R32.2, R46.1, TP7.TP, U6.1
unnamed: R37.2, R38.1, TP3.TP, U4.7
unnamed: R48.2, R49.1, TP8.TP, U6.7
unnamed: R26.2, U4.3 (+)
unnamed: R28.1, R33.2, U4.2 (-)
unnamed: R34.2, R35.2, U4.5 (+)
unnamed: R36.2, R37.1, U4.6 (-)
unnamed: C15.1, R39.2, U5.3 (+)
unnamed: R40.1, R42.2, U5.2 (-)
unnamed: C26.1, R44.2, U5.5 (+)
unnamed: R41.1, R58.2, U5.6 (-)
unnamed: R30.2, U6.3 (+)
unnamed: R31.2, R32.1, U6.2 (-)
unnamed: R45.2, R46.2, U6.5 (+)
unnamed: R47.2, R48.1, U6.6 (-)
unnamed: C16.1, R50.2, U7.3 (+)
unnamed: R51.2, R52.1, U7.2 (-)
unnamed: C29.1, R54.2, U7.5 (+)
unnamed: R55.1, R59.2, U7.6 (-)
unnamed: R56.2, R60.2, U9.3 (VIN)
unnamed: R57.2, R61.2, U10.3 (VIN)

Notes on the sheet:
Unity Gain, Adds Offset From: 0V center To: 2.5V center
Anti Aliasing LPF
Input Buffer Gain = 6dB

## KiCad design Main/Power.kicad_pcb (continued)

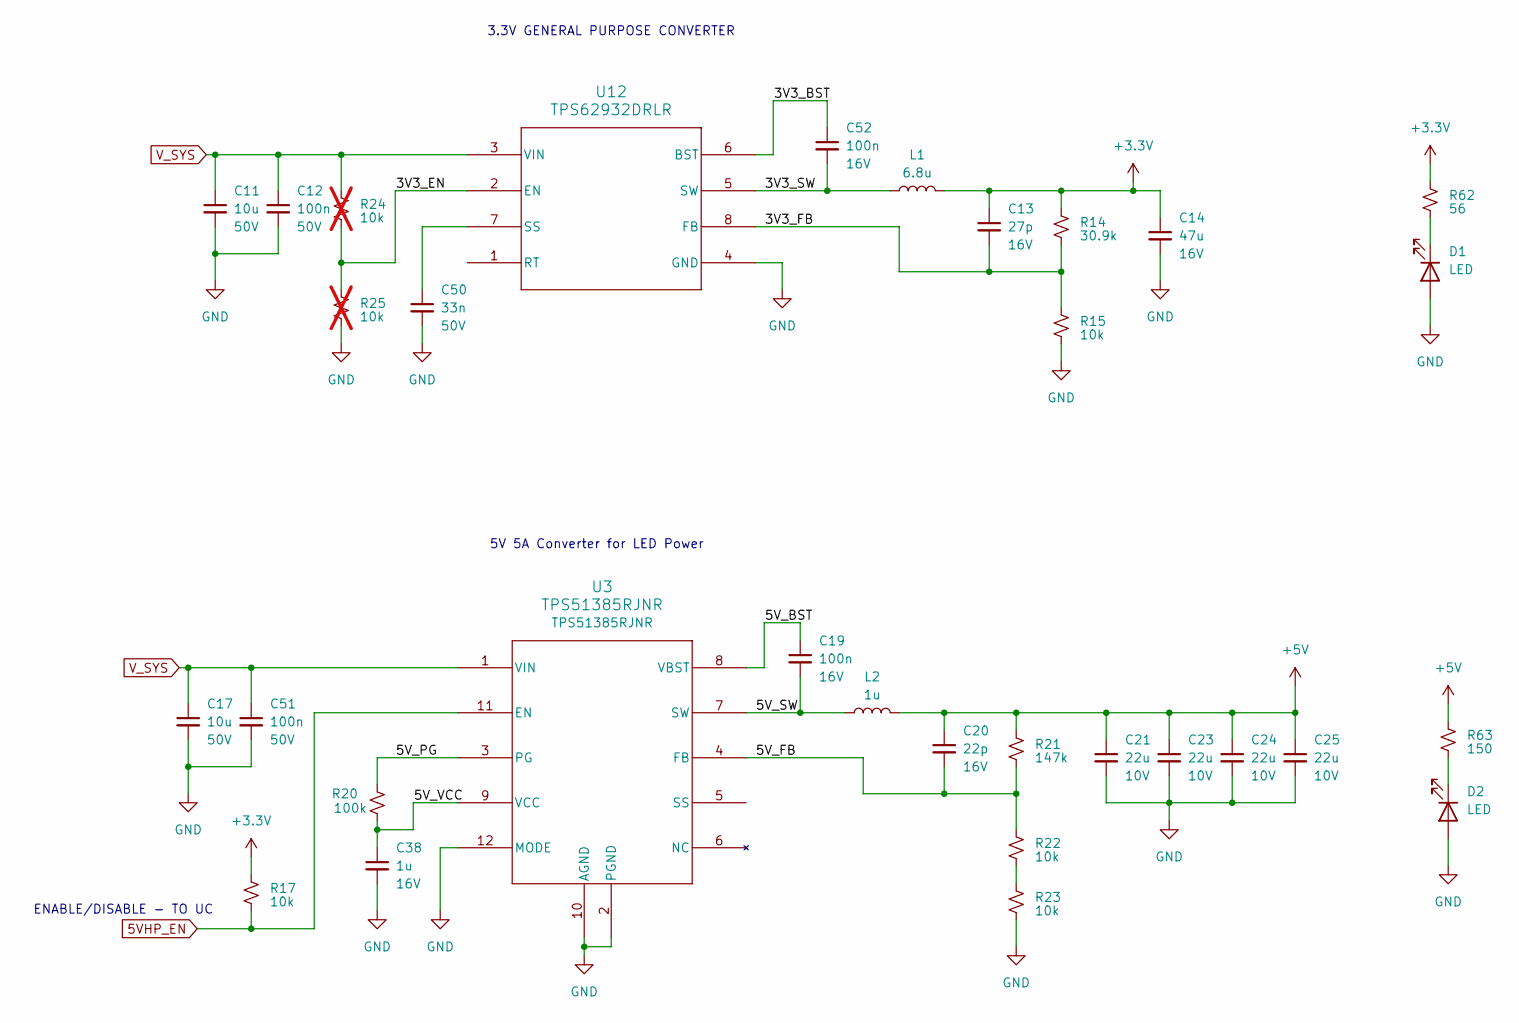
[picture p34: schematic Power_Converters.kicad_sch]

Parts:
C11, C17: 10u; C_1206_3216Metric_Pad1.33x1.80mm_HandSolder; Voltage 50V; Part Number C3216X5R1H106K160AB
C12, C51: 100n; C_0805_2012Metric_Pad1.18x1.45mm_HandSolder; Voltage 50V; Part Number GRM21BR71H104KA01L
C13: 27p; C_0805_2012Metric_Pad1.18x1.45mm_HandSolder; Voltage 16V; Part Number 0805YA270JAT2A
C14: 47u; C_1210_3225Metric_Pad1.33x2.70mm_HandSolder; Voltage 16V; Part Number GRM32ER61C476KE15L
C19, C52: 100n; C_0805_2012Metric_Pad1.18x1.45mm_HandSolder; Voltage 16V; Part Number 0805YC104MAT2A
C20: 22p; C_0805_2012Metric_Pad1.18x1.45mm_HandSolder; Voltage 16V; Part Number 0805YA220JAT2A
C21, C23, C24, C25: 22u; C_1206_3216Metric_Pad1.33x1.80mm_HandSolder; Voltage 10V; Part Number GRM31CR71A226KE15L
C38: 1u; C_0805_2012Metric_Pad1.18x1.45mm_HandSolder; Voltage 16V; Part Number GCJ21BR71C105KA01L
C50: 33n; C_0805_2012Metric_Pad1.18x1.45mm_HandSolder; Voltage 50V; Part Number GRM21BR71H104KA01L
D1, D2: LED; LED_0805_2012Metric_Pad1.15x1.40mm_HandSolder; Part Number APT2012PGW
L1: 6.8u; L_Coilcraft_XAL7070-XXX; Part Number XAL7070-682MEB
L2: 1u; L_Coilcraft_XAL6030-XXX; Part Number XAL6030-102MEB
R14: 30.9k; R_0805_2012Metric_HandSolder; Part Number CRCW080530K9FKEA
R15, R17, R22, R23: 10k; R_0805_2012Metric_HandSolder; Part Number CRCW080510K0FKEA
R20: 100k; R_0805_2012Metric_HandSolder; Part Number CRCW0805100KFKEA
R21: 147k; R_0805_2012Metric_HandSolder; Part Number CRCW0805147KFKEA
R24, R25: 10k; R_0805_2012Metric_HandSolder; Part Number CRCW080510K0FKEA; not fitted
R62: 56; R_0805_2012Metric_HandSolder; Part Number CRCW080556R0FKEA
R63: 150; R_0805_2012Metric_HandSolder; Part Number CRCW0805150RFKEA
U3: TPS51385RJNR; VQFN-HR12_RJN_TEX; Part Number TPS51385RJNR
U12: TPS62932DRLR; SOT8_DRL_TEX; Part Number TPS62932DRLR

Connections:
5VHP_EN: R17.2, U3.11 (EN); also elsewhere on the board
+3.3V: C13.1, C14.1, L1.2, R14.1, R17.1, R62.1; also elsewhere on the board
+5V: C20.1, C21.1, C23.1, C24.1, C25.1, L2.2, R21.1, R63.1; also elsewhere on the board
/Power_Converters/3V3_BST: C52.1, U12.6 (BST)
/Power_Converters/3V3_EN: R24.2, R25.1, U12.2 (EN)
/Power_Converters/3V3_FB: C13.2, R14.2, R15.1, U12.8 (FB)
/Power_Converters/3V3_SW: C52.2, L1.1, U12.5 (SW)
/Power_Converters/5V_BST: C19.1, U3.8 (VBST)
/Power_Converters/5V_FB: C20.2, R21.2, R22.1, U3.4 (FB)
/Power_Converters/5V_PG: R20.1, U3.3 (PG)
/Power_Converters/5V_SW: C19.2, L2.1, U3.7 (SW)
/Power_Converters/5V_VCC: C38.1, R20.2, U3.9 (VCC)
GND: C11.2, C12.2, C14.2, C17.2, C21.2, C23.2, C24.2, C25.2, C38.2, C50.2, C51.2, D1.2 (A), D2.2 (A), R15.2, R23.2, R25.2, U3.2 (PGND), U3.10 (AGND), U3.12 (MODE), U12.4 (GND); also elsewhere on the board
unnamed: D1.1 (K), R62.2
unnamed: D2.1 (K), R63.2
unnamed: R22.2, R23.1
unnamed: C50.1, U12.7 (SS)
V_SYS: C11.1, C12.1, C17.1, C51.1, R24.1, U3.1 (VIN), U12.3 (VIN); also elsewhere on the board

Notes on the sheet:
5V 5A Converter for LED Power
ENABLE/DISABLE - TO UC
3.3V GENERAL PURPOSE CONVERTER

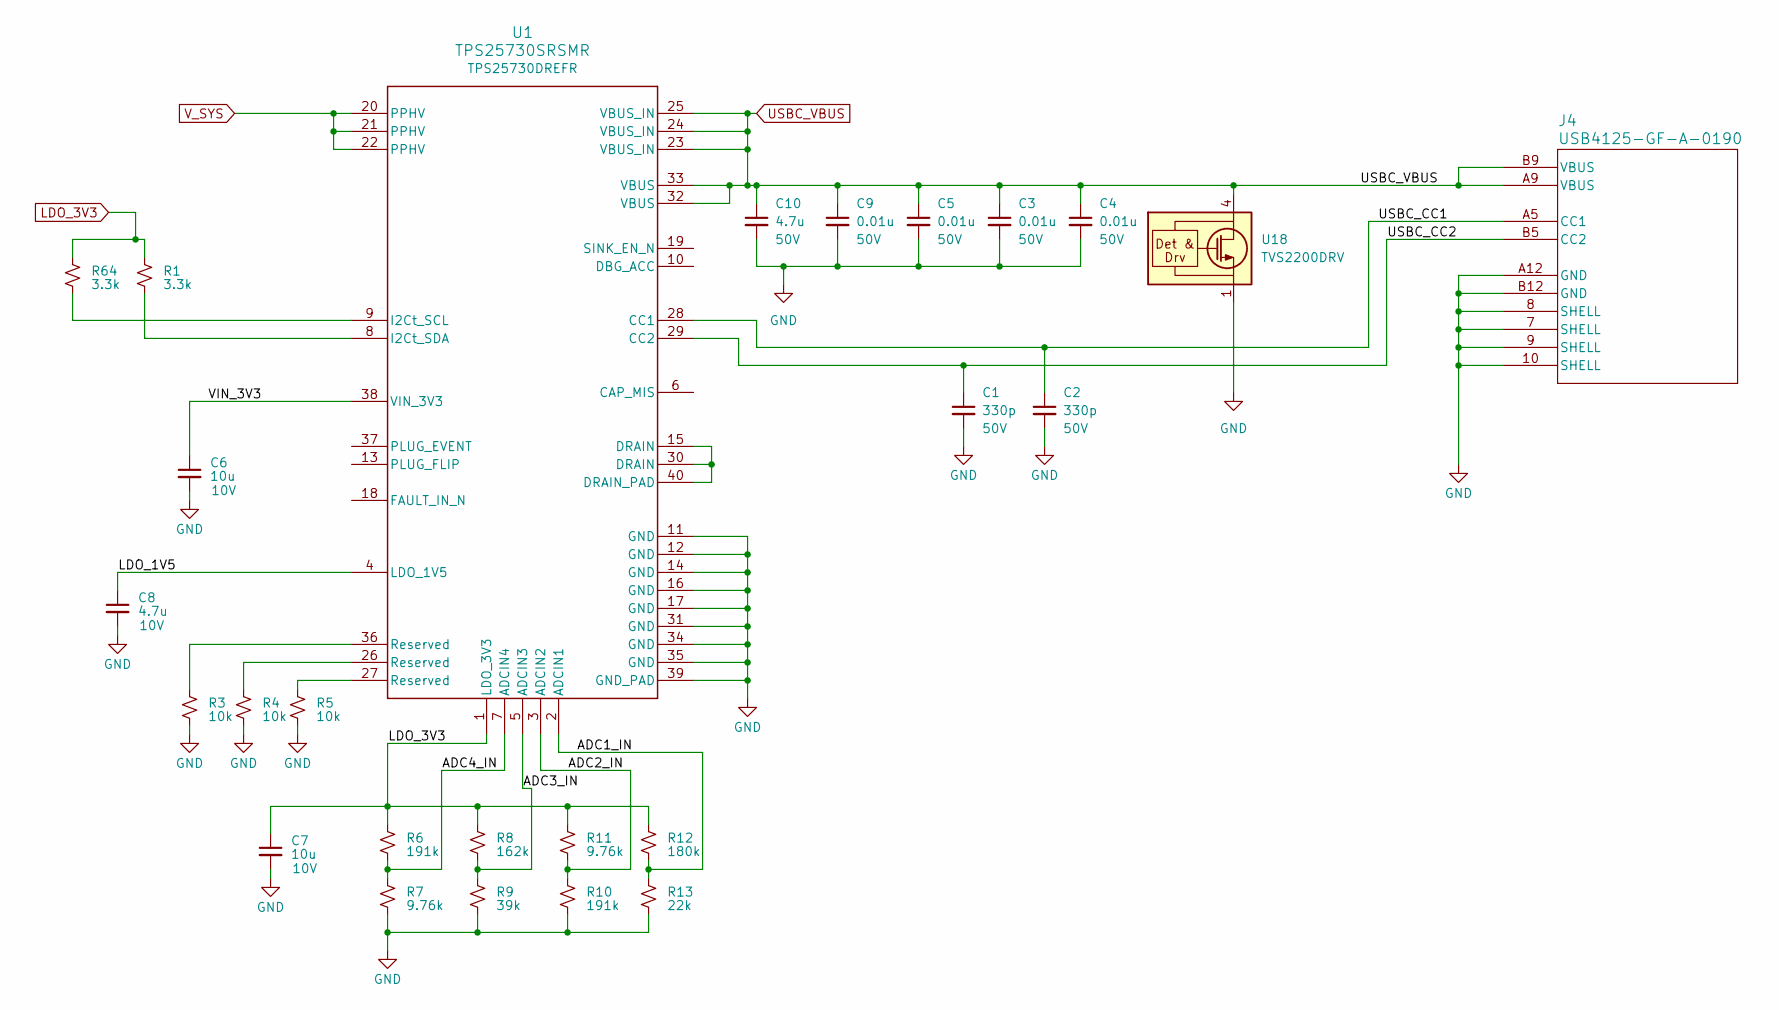
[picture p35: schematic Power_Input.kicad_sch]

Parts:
C1, C2: 330p; C_0805_2012Metric_Pad1.18x1.45mm_HandSolder; Voltage 50V; Part Number 08055A331GAT2A
C3, C4, C5, C9: 0.01u; C_0805_2012Metric_Pad1.18x1.45mm_HandSolder; Voltage 50V; Part Number 08055C103ZAT2A
C6, C7: 10u; C_0805_2012Metric_Pad1.18x1.45mm_HandSolder; Voltage 10V; Part Number MBASL21GBB7106KTNA18
C8: 4.7u; C_0805_2012Metric_Pad1.18x1.45mm_HandSolder; Voltage 10V; Part Number GRM219R61A475KE32D
C10: 4.7u; C_0805_2012Metric_Pad1.18x1.45mm_HandSolder; Voltage 50V; Part Number GRM21BC71H475KE11K
J4: USB4125-GF-A-0190; CONN6_125-GF-A-0190_GCT; Part Number USB4125-GF-A-0190
R1, R64: 3.3k; R_0805_2012Metric_Pad1.20x1.40mm_HandSolder; Part Number CRCW08053K30FKEA
R3, R4, R5: 10k; R_0805_2012Metric_HandSolder; Part Number CRCW080510K0FKEA
R6, R10: 191k; R_0805_2012Metric_HandSolder; Part Number CRCW0805191KFKEA
R7, R11: 9.76k; R_0805_2012Metric_HandSolder; Part Number CRCW08059K76FKEA
R8: 162k; R_0805_2012Metric_HandSolder; Part Number CRCW0805162KFKEA
R9: 39k; R_0805_2012Metric_HandSolder; Part Number CRCW080539K0FKEA
R12: 180k; R_0805_2012Metric_HandSolder; Part Number CRCW0805180KFKEA
R13: 22k; R_0805_2012Metric_HandSolder; Part Number CRCW080522K0FKEA
U1: TPS25730SRSMR; REF0038A-MFG; Part Number TPS25730DREFR
U18: TVS2200DRV; WSON-6-1EP_2x2mm_P0.65mm_EP1x1.6mm; Part Number TVS2200DRV

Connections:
/Power_Input/ADC1_IN: R12.2, R13.1, U1.2 (ADCIN1)
/Power_Input/ADC2_IN: R10.1, R11.2, U1.3 (ADCIN2)
/Power_Input/ADC3_IN: R8.2, R9.1, U1.5 (ADCIN3)
/Power_Input/ADC4_IN: R6.2, R7.1, U1.7 (ADCIN4)
/Power_Input/LDO_1V5: C8.1, U1.4 (LDO_1V5)
/Power_Input/USBC_CC1: C2.1, J4.A5 (CC1), U1.28 (CC1)
/Power_Input/USBC_CC2: C1.1, J4.B5 (CC2), U1.29 (CC2)
/Power_Input/VIN_3V3: C6.1, U1.38 (VIN_3V3)
GND: C1.2, C2.2, C3.2, C4.2, C5.2, C6.2, C7.2, C8.2, C9.2, C10.2, J4.7 (SHELL), J4.8 (SHELL), J4.9 (SHELL), J4.10 (SHELL), J4.A12 (GND), J4.B12 (GND), R3.2, R4.2, R5.2, R7.2, R9.2, R10.2, R13.2, U1.11 (GND), U1.12 (GND), U1.14 (GND), U1.16 (GND), U1.17 (GND), U1.31 (GND), U1.34 (GND), U1.35 (GND), U1.39 (GND_PAD), U18.1 (GND), U18.2 (GND), U18.3 (GND), U18.7 (GND); also elsewhere on the board
LDO_3V3: C7.1, R1.1, R6.1, R8.1, R11.1, R12.1, R64.1, U1.1 (LDO_3V3)
unnamed: R3.1, U1.36 (Reserved)
unnamed: R4.1, U1.26 (Reserved)
unnamed: R5.1, U1.27 (Reserved)
unnamed: U1.15 (DRAIN), U1.30 (DRAIN), U1.40 (DRAIN_PAD)
unnamed: R64.2, U1.9 (I2Ct_SCL)
unnamed: R1.2, U1.8 (I2Ct_SDA)
USBC_VBUS: C3.1, C4.1, C5.1, C9.1, C10.1, J4.A9 (VBUS), J4.B9 (VBUS), U1.23 (VBUS_IN), U1.24 (VBUS_IN), U1.25 (VBUS_IN), U1.32 (VBUS), U1.33 (VBUS), U18.4 (IN), U18.5 (IN), U18.6 (IN)
V_SYS: U1.20 (PPHV), U1.21 (PPHV), U1.22 (PPHV); also elsewhere on the board

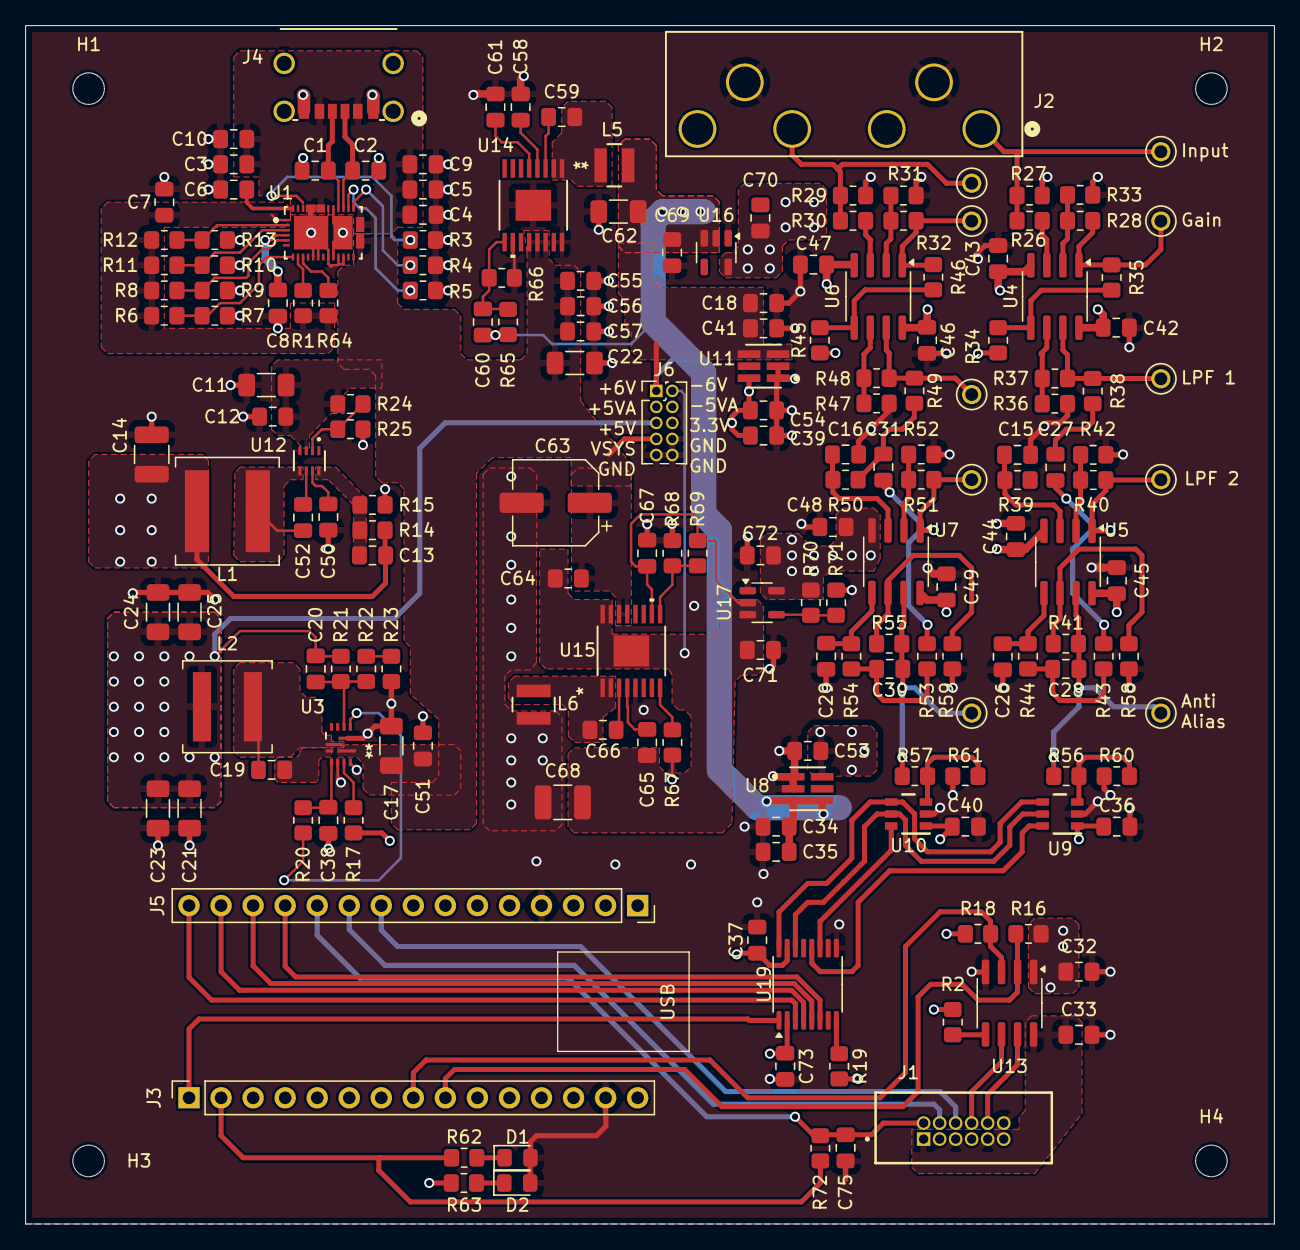
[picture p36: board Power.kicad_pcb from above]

Board: 4 copper layers, 99.0 x 95.0 mm, 190 parts (1 on the bottom side), 100 nets.

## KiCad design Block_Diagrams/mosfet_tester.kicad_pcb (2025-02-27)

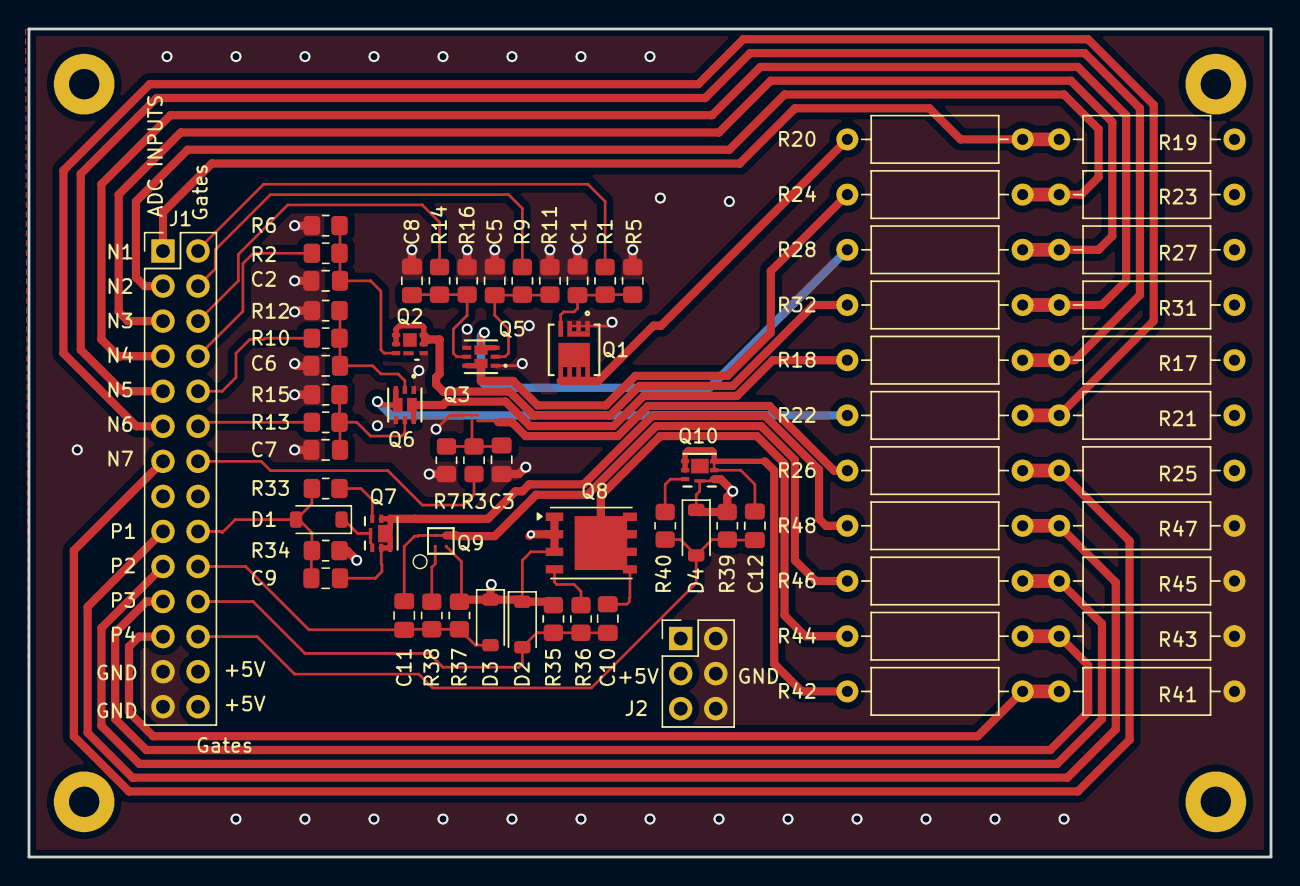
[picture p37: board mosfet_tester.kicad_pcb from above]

Board: 2 copper layers, 90.0 x 60.0 mm, 70 parts (0 on the bottom side), 46 nets.

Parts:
C1, C2, C3, C5, C6, C7, C8, C9, C10, C11, C12: 1000p; C_0805_2012Metric_Pad1.18x1.45mm_HandSolder
D1, D2, D3, D4: MMSZ5238BT1G; D_SOD-123
J1: Conn_02x14_Odd_Even; PinHeader_2x14_P2.54mm_Vertical
J2: Conn_02x03_Odd_Even; PinHeader_2x03_P2.54mm_Vertical
Q1: IPZ40N04S5L7R4ATMA1; PG-TSDSON-8-32_INF
Q2: CSD17318Q2T; DQK6_TEX
Q3: SI8812DB-T2-E1; MICROFOOT4_0P8X0P8-0P4_VIS
Q5: IRLHS6376TRPBF; PQFN6_IRLHS6376TRPBF_INF
Q6: SIA918EDJ-T1-GE3; SON_EDJ-T1-GE3_VIS
Q7: IRLHS2242TRPBF; PQFN6_2X2_INF
Q8: SI7489DP-T1-GE3; PowerPAK_SO-8_Single
Q9: SI8409DB-T1-E1; MICROFOOT4_1p6X1p6-0p8_VIS
Q10: SQA413CEJW-T1_GE3; PQFN6_2X2_INF
R1, R2, R3, R9, R10, R13, R14, R33, R36, R38, R40: 47; R_0805_2012Metric_HandSolder
R5, R6, R7, R11, R12, R15, R16, R34, R35, R37, R39: 10K; R_0805_2012Metric_HandSolder
R17, R18, R19, R20, R21, R22, R23, R24, R25, R26, R27, R28, R31, R32, R41, R42, R43, R44, R45, R46, R47, R48: 10; R_Axial_DIN0309_L9.0mm_D3.2mm_P12.70mm_Horizontal

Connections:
+5V: D1.1 (K), D2.1 (K), D3.1 (K), D4.1 (K), J1.26, J1.28, J2.1, J2.3, J2.5, Q7.4 (S), Q7.8 (S), Q8.1 (S), Q8.2 (S), Q8.3 (S), Q9.4 (S), Q10.4 (S), Q10.7 (S), R17.1, R19.1, R21.1, R23.1, R25.1, R27.1, R31.1, R34.1, R35.1, R37.1, R39.1
GND: C1.2, C2.2, C3.2, C5.2, C6.2, C7.2, C8.2, J1.25, J1.27, J2.2, J2.4, J2.6, Q1.1 (S), Q1.2 (S), Q1.3 (S), Q2.4 (S), Q3.2 (S), Q3.3 (S), Q5.1 (S1), Q5.4 (S2), Q6.1 (S1), Q6.4 (S2), R5.2, R6.2, R7.2, R11.2, R12.2, R15.2, R16.2, R41.2, R43.2, R45.2, R47.2
N1_GATE: J1.2, R1.1
N1_LOAD: Q1.5 (D), Q1.6 (D), Q1.7 (D), Q1.8 (D), R20.2
N2_GATE: J1.4, R9.1
N2_LOAD: Q5.6 (D1), Q5.7 (D1), R24.2
N3_GATE: J1.6, R14.1
N3_LOAD: Q5.3 (D2), Q5.8 (D2), R28.2
N4_GATE: J1.8, R2.1
N4_LOAD: Q2.1 (D), Q2.2 (D), Q2.5 (D), Q2.6 (D), R32.2
N5_GATE: J1.10, R10.1
N5_LOAD: Q6.6 (D1), Q6.7 (D1), R18.2
N6_GATE: J1.12, R13.1
N6_LOAD: Q6.3 (D2), Q6.8 (D2), R22.2
N7_GATE: J1.14, R3.1
N7_LOAD: Q3.4 (D), R26.2
unnamed: J1.1, R19.2, R20.1
unnamed: J1.3, R23.2, R24.1
unnamed: J1.5, R27.2, R28.1
unnamed: J1.7, R31.2, R32.1
unnamed: J1.9, R17.2, R18.1
unnamed: J1.11, R21.2, R22.1
unnamed: J1.13, R25.2, R26.1
unnamed: J1.17, R47.1, R48.1
unnamed: J1.19, R45.1, R46.1
unnamed: J1.21, R43.1, R44.1
unnamed: J1.23, R41.1, R42.1
unnamed: C1.1, Q1.4 (G), R1.2, R5.1
unnamed: C2.1, Q2.3 (G), R2.2, R6.1
unnamed: C3.1, Q3.1 (G), R3.2, R7.1
unnamed: C5.1, Q5.2 (G1), R9.2, R11.1
unnamed: C8.1, Q5.5 (G2), R14.2, R16.1
unnamed: C6.1, Q6.2 (G1), R10.2, R12.1
unnamed: C7.1, Q6.5 (G2), R13.2, R15.1
unnamed: Q7.3 (G), R33.2
unnamed: Q8.4 (G), R36.2
unnamed: Q9.1 (G), R38.2
unnamed: Q10.3 (G), R40.2
P1_GATE: C9.2, D1.2 (A), J1.18, R33.1, R34.2
P1_LOAD: C9.1, Q7.1 (D), Q7.2 (D), Q7.5 (D), Q7.6 (D), Q7.7 (D), R48.2
P2_GATE: C11.2, D3.2 (A), J1.20, R37.2, R38.1
P2_LOAD: C11.1, Q9.2 (D), Q9.3 (D), R46.2
P3_GATE: C10.2, D2.2 (A), J1.22, R35.2, R36.1
P3_LOAD: C10.1, Q8.5 (D), R44.2
P4_GATE: C12.2, D4.2 (A), J1.24, R39.2, R40.1
P4_LOAD: C12.1, Q10.1 (D), Q10.2 (D), Q10.5 (D), Q10.6 (D), R42.2

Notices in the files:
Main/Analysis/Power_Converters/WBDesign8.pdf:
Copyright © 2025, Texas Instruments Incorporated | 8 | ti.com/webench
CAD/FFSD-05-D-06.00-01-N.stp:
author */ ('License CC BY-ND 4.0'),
